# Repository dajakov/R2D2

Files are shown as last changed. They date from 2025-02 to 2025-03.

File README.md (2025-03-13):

# R2D2 Robotic Control System

<div style="display: flex; justify-content: space-between;">
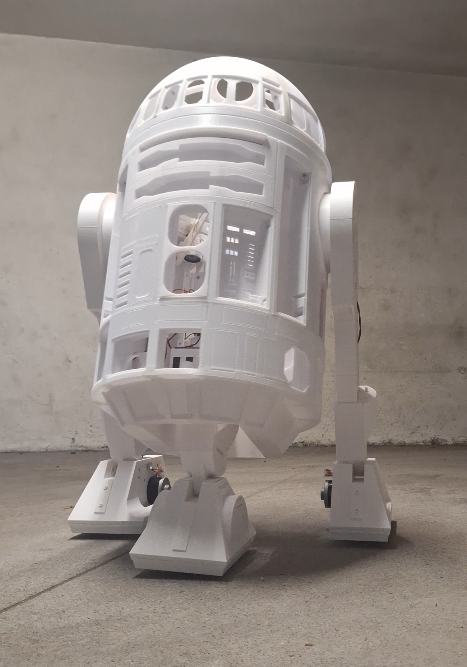
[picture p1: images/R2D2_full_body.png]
  
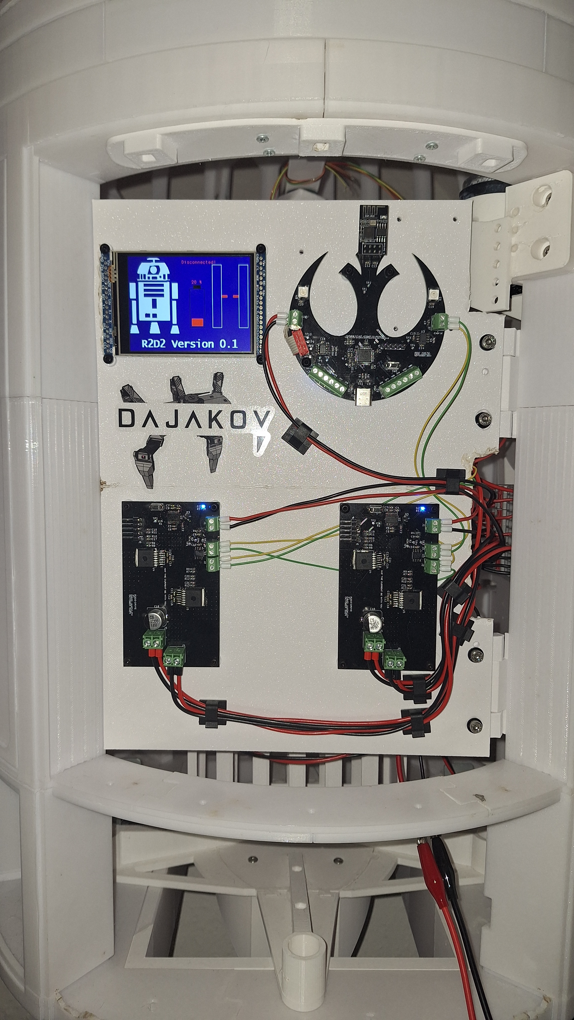
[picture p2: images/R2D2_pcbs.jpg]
  
</div>

This repository contains all source files for a robotic control system designed to control a life-sized R2D2 robot. The 3D models were created by  [Michael Baddeley](https://www.patreon.com/mrbaddeley).

I initiated this project due to the need for a smart and reliable way to control R2D2 via an Android app. I began developing a simple proof-of-concept app in Android Studio, featuring:

- A joystick for velocity control
- Two buttons to rotate the dome
- A text field to display debugging messages

The communication between the hardware and the app occurs via a WebSocket connection to an ESP01.

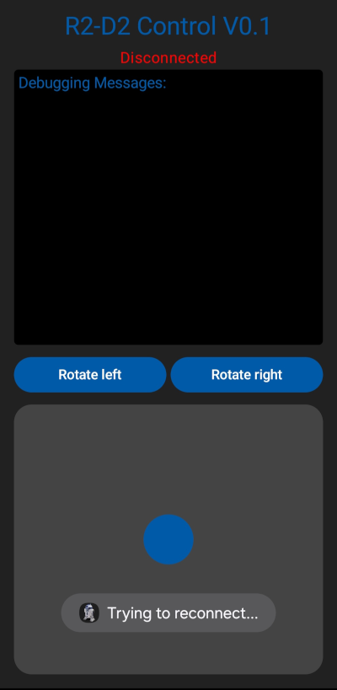
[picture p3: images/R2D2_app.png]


# Hardware

I designed multiple subsystems, each with its own PCB. The brain of every subsystem is a STM32 microcontroller, responsible for fulfilling unique tasks. These PCBs communicate with each other via CAN-bus.

The main PCB serves as the translator for incoming data from the Android app, converting it into low-level commands for the subsystems which control the actual hardware. 

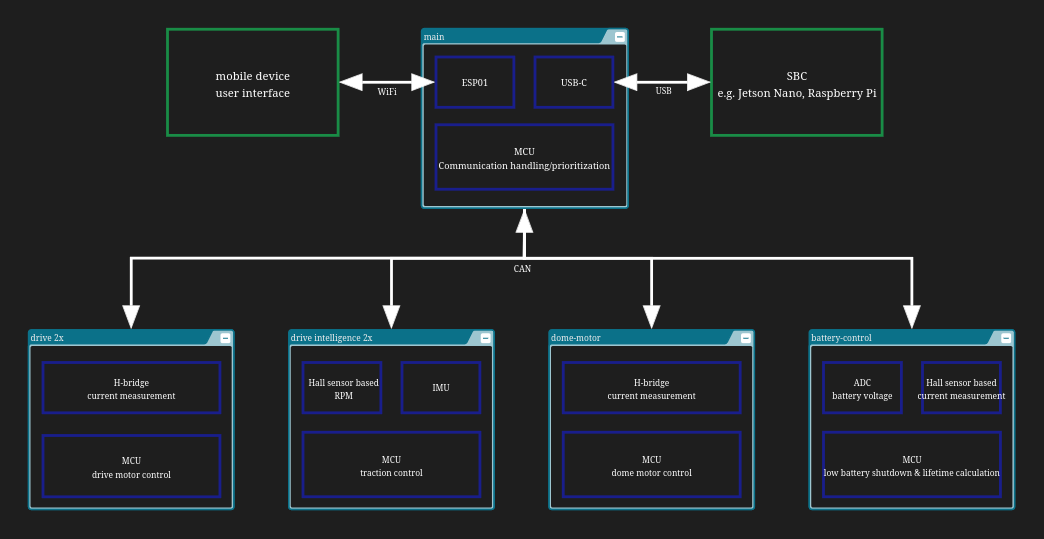
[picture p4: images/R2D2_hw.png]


# Firmware

The STM32 microcontrollers were programmed using STM32CubeIDE. This repository contains the entire CubeIDE project directory for each subsystem.
Each PCB features a 2.54mm male pin header, allowing for easy flashing and debugging via SWD (Serial Wire Debug).

# Development

Hardware:
- [x] Test main PCB
- [x] Test drive PCB
- [ ] Test dome-motor PCB
- [x] Test drive-intelligence PCB
- [ ] Test battery-control PCB

Firmware:
- [x] Velocity control 
- [x] Shut down motors on connection loss to Android App
- [x] Increase CAN frequency

Android App:
- [x] Joystick
- [x] Buttons for dome rotation
- [ ] Add status display (battery state, error indicator)

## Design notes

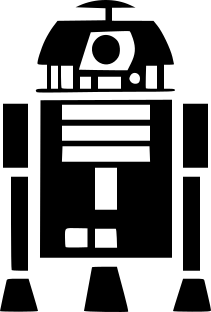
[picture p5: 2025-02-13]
firmware/R2D2 - Main/r2d2-bitmap.bmp

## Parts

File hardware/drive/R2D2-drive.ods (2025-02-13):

Reference | Value | Datasheet | Footprint | Qty | DNP
C1,C3 | 10u | ~ | Capacitor_SMD:C_0603_1608Metric_Pad1.08x0.95mm_HandSolder | 2
C2 | 4.7u | ~ | Capacitor_SMD:C_0603_1608Metric_Pad1.08x0.95mm_HandSolder | 1
C4,C5,C6,C8,C9,C10,C11,C12,C13,C14,C15,C16,C17,C20 | 100n | ~ | Capacitor_SMD:C_0603_1608Metric_Pad1.08x0.95mm_HandSolder | 14
C7 | 1u | ~ | Capacitor_SMD:C_0603_1608Metric_Pad1.08x0.95mm_HandSolder | 1
C18 | 1000u | ~ | Capacitor_SMD:CP_Elec_10x10.5 | 1
C19,C21 | 1n | ~ | Capacitor_SMD:C_0603_1608Metric_Pad1.08x0.95mm_HandSolder | 2
D1 | 1N4001 | ~ | Diode_SMD:D_SMA_Handsoldering | 1
D2 | LED | ~ | LED_SMD:LED_0603_1608Metric_Pad1.05x0.95mm_HandSolder | 1
D3 | BAT54C | http://www.diodes.com/_files/datasheets/ds11005.pdf | Package_TO_SOT_SMD:SOT-23 | 1
J1,J2,J3 | 1751248 |  | 1751248:PHOENIX_1751248 | 3
J4,J5 | 1935776 |  | 1935776:PHOENIX_1935776 | 2
J6 | Conn_01x05_Pin | ~ | Connector_PinHeader_2.54mm:PinHeader_1x05_P2.54mm_Horizontal | 1
R1,R2,R6,R7,R8,R9 | 10k | ~ | Resistor_SMD:R_0603_1608Metric_Pad0.98x0.95mm_HandSolder | 6
R3 | 560 | ~ | Resistor_SMD:R_0603_1608Metric_Pad0.98x0.95mm_HandSolder | 1
R4 | 0 | ~ | Resistor_SMD:R_0603_1608Metric_Pad0.98x0.95mm_HandSolder | 1
R10,R12 | 5k1 | ~ | Resistor_SMD:R_0603_1608Metric_Pad0.98x0.95mm_HandSolder | 2
R11,R13 | 1k | ~ | Resistor_SMD:R_0603_1608Metric_Pad0.98x0.95mm_HandSolder | 2
SW1 | PTS636 SM50J SMTR LFS | PTS636 SM50J SMTR LFS | PTS636:SW_PTS636_CNK | 1
TP1,TP2,TP3,TP4 | TestPoint | ~ | TestPoint:TestPoint_Pad_D1.0mm | 4
U1 | LM1117MP-3.3 | http://www.ti.com/lit/ds/symlink/lm1117.pdf | Package_TO_SOT_SMD:SOT-223-3_TabPin2 | 1
U2 | STM32F042F6Px | https://www.st.com/resource/en/datasheet/stm32f042f6.pdf | Package_SO:TSSOP-20_4.4x6.5mm_P0.65mm | 1
U3 | SN65HVD230 | http://www.ti.com/lit/ds/symlink/sn65hvd230.pdf | Package_SO:SOIC-8_3.9x4.9mm_P1.27mm | 1
U4,U5 | BTN8962TAAUMA1 | BTN8962TAAUMA1 | BTN8962TAAUMA1:PG-TO263-7-1_INF | 2

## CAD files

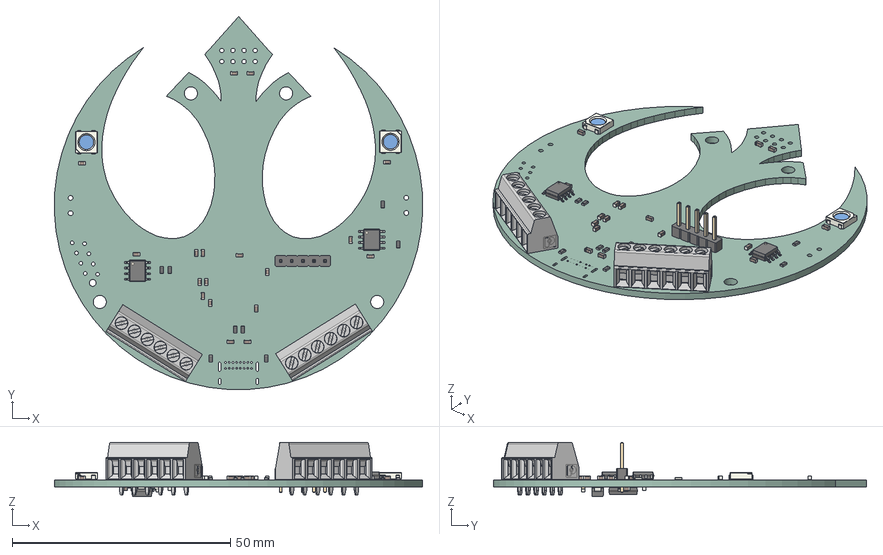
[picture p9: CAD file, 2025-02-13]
hardware/main/R2D2-Main.step
84.3 x 85.4 x 12.5 mm
R_0603_1608Metric x 9
C_0603_1608Metric x 20
LED_WS2812B_PLCC4_50x50mm_P32mm x 2
PinHeader_1x05_P254mm_Vertical
mkds_1-6-3.5 x 2
SOIC_8_39x49mm_P127mm x 2
LED_0603_1608Metric
D_SMA
SOT_223
R2D2-Main_PCB

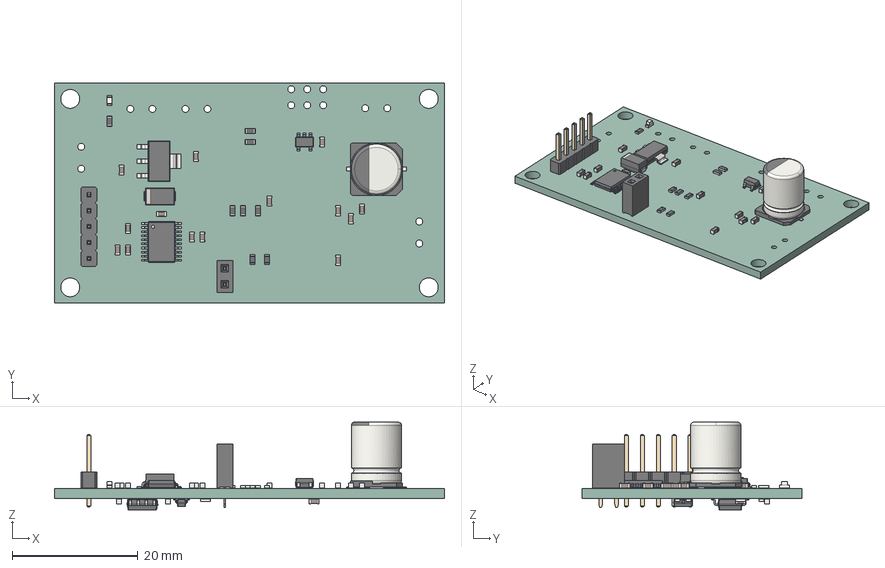
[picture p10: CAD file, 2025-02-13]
hardware/dome-motor/R2D2-dome-motor.step
62.0 x 35.0 x 14.0 mm
C_0603_1608Metric x 17
SOT_23_5
R_0603_1608Metric x 12
TSSOP_20_44x65mm_P065mm
PinHeader_1x05_P254mm_Vertical
SOT_223
LED_0603_1608Metric
CP_Elec_8x105
D_SMA
PinSocket_1x02_P254mm_Vertical
SOIC_8_39x49mm_P127mm
SOT_23
R2D2-dome-motor_PCB

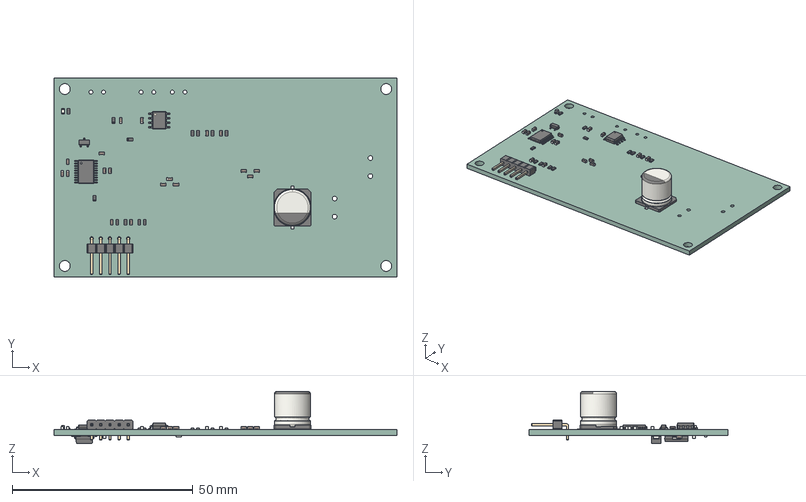
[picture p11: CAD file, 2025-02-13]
hardware/drive/R2D2-drive.step
95.0 x 55.0 x 14.4 mm
CP_Elec_10x105
R_0603_1608Metric x 13
C_0603_1608Metric x 20
SOIC_8_39x49mm_P127mm
PinHeader_1x05_P254mm_Horizontal
LED_0603_1608Metric
TSSOP_20_44x65mm_P065mm
SOT_23
D_SMA
SOT_223
R2D2-drive_PCB

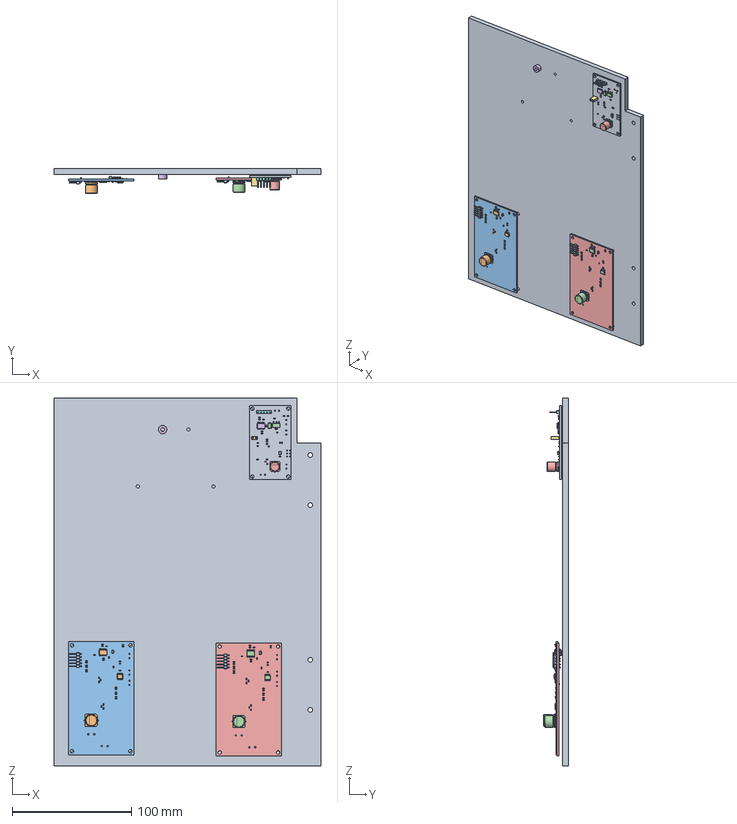
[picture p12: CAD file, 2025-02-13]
hardware/main/Unnamed.FCStd
224.0 x 21.2 x 309.0 mm
C_0603_1608Metric040
C_0603_1608Metric042
SOT_23_5
R_0603_1608Metric018
TSSOP_20_44x65mm_P065mm
C_0603_1608Metric044
PinHeader_1x05_P254mm_Vertical001
R_0603_1608Metric020
R_0603_1608Metric022
R_0603_1608Metric024
SOT_224
R_0603_1608Metric026
C_0603_1608Metric046
C_0603_1608Metric048
C_0603_1608Metric050
LED_0603_1608Metric002
C_0603_1608Metric052
C_0603_1608Metric054
R_0603_1608Metric028
CP_Elec_8x105
C_0603_1608Metric056
C_0603_1608Metric058
C_0603_1608Metric060
R_0603_1608Metric030
R_0603_1608Metric032
C_0603_1608Metric062
D_SMA002
C_0603_1608Metric064
C_0603_1608Metric066
PinSocket_1x02_P254mm_Vertical
C_0603_1608Metric068
R_0603_1608Metric034
R_0603_1608Metric036
R_0603_1608Metric038
C_0603_1608Metric070
C_0603_1608Metric072
SOIC_8_39x49mm_P127mm002
R_0603_1608Metric040
SOT_23
R2D2-dome-motor_PCB
CP_Elec_10x105
R_0603_1608Metric042
C_0603_1608Metric074
R_0603_1608Metric044
R_0603_1608Metric046
R_0603_1608Metric048
R_0603_1608Metric050
C_0603_1608Metric076
SOIC_8_39x49mm_P127mm003
C_0603_1608Metric078
R_0603_1608Metric052
C_0603_1608Metric080
R_0603_1608Metric054
C_0603_1608Metric082
R_0603_1608Metric056
PinHeader_1x05_P254mm_Horizontal
R_0603_1608Metric058
C_0603_1608Metric084
R_0603_1608Metric060
C_0603_1608Metric086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

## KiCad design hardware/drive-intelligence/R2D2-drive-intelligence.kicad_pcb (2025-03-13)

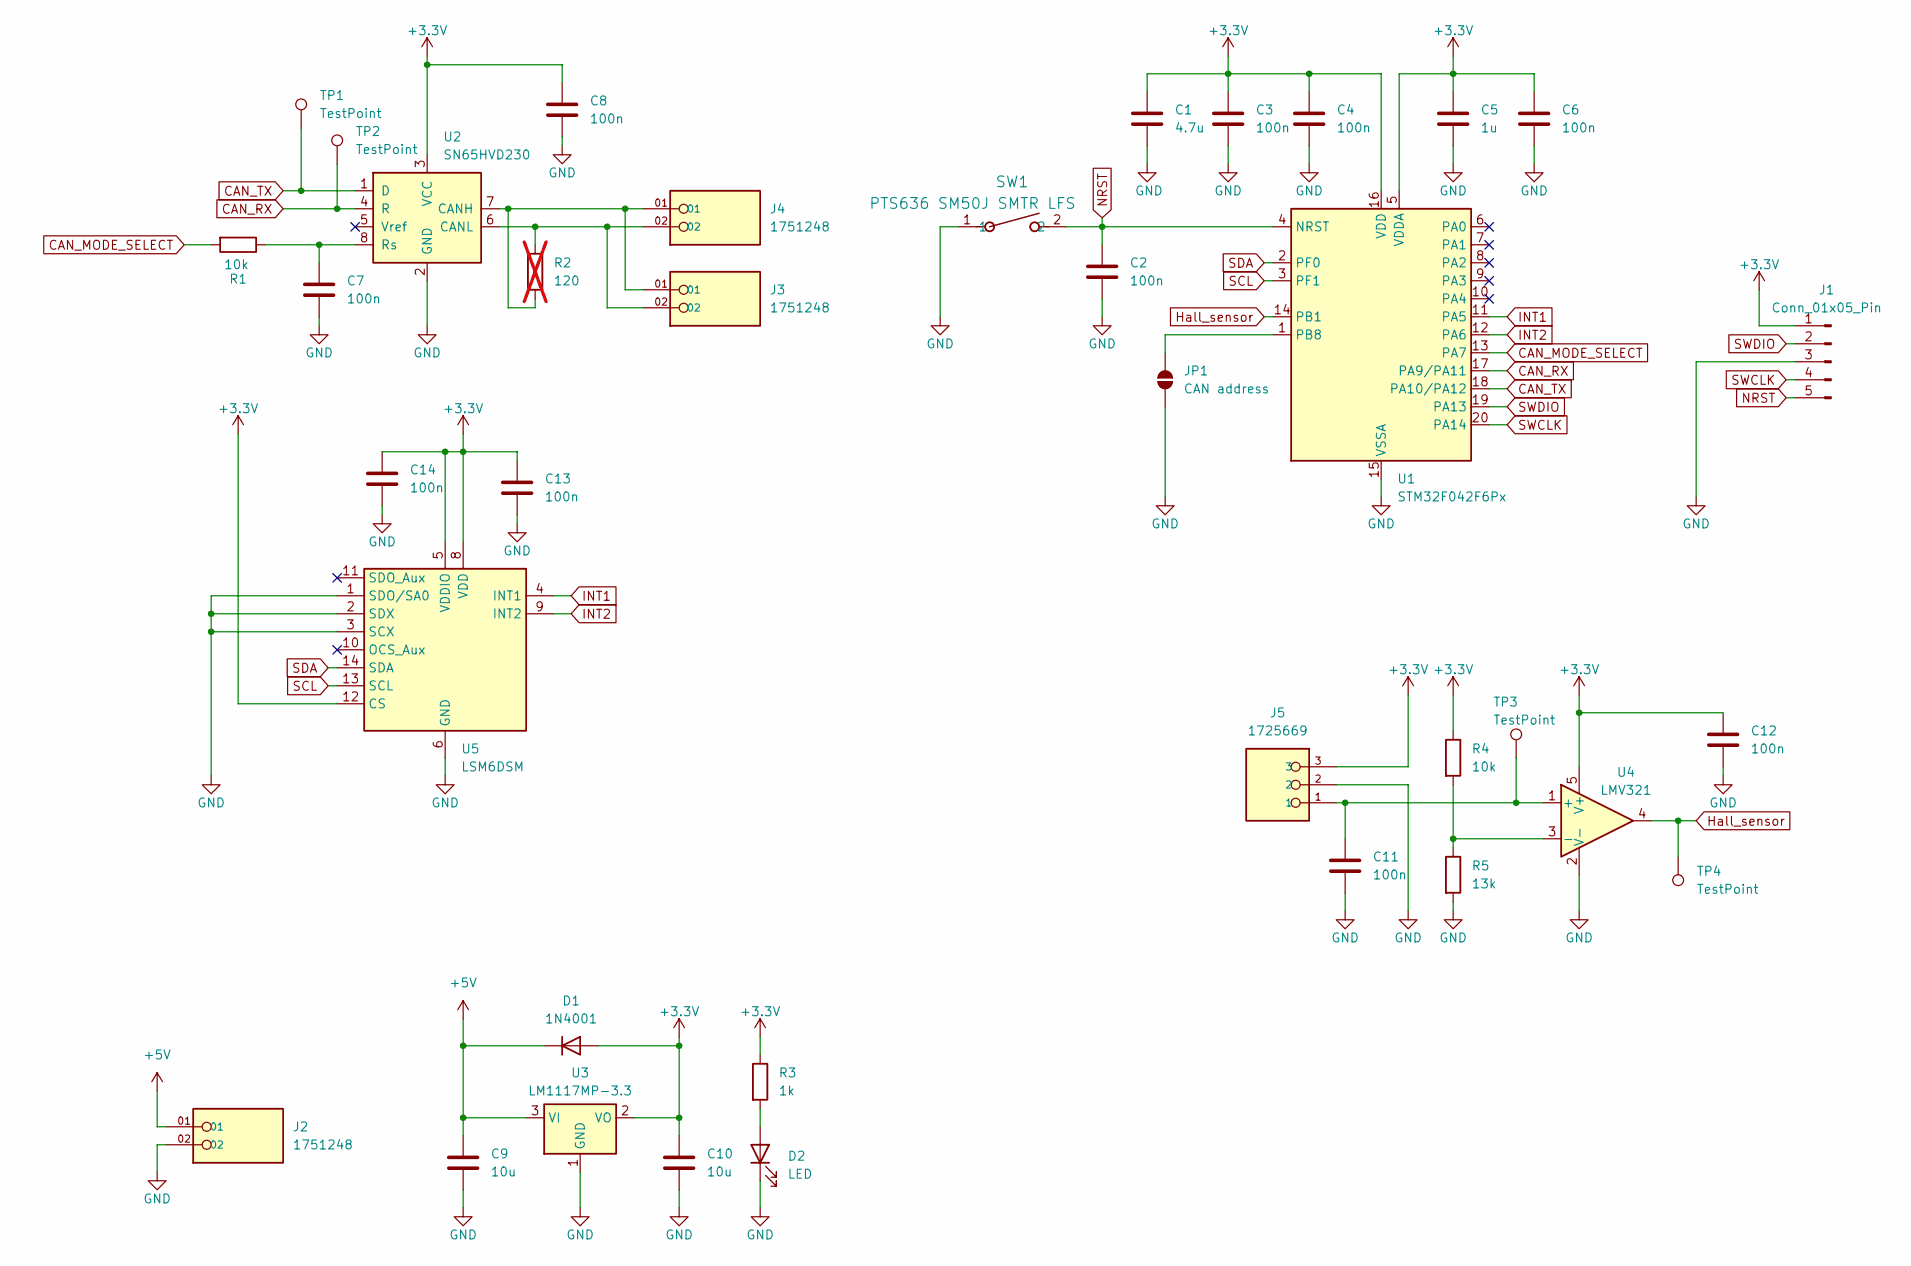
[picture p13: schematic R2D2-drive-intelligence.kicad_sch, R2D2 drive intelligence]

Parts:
C1: 4.7u; C_0603_1608Metric_Pad1.08x0.95mm_HandSolder
C2, C3, C4, C6, C7, C8, C11, C12, C13, C14: 100n; C_0603_1608Metric_Pad1.08x0.95mm_HandSolder
C5: 1u; C_0603_1608Metric_Pad1.08x0.95mm_HandSolder
C9, C10: 10u; C_0603_1608Metric_Pad1.08x0.95mm_HandSolder
D1: 1N4001; D_SMA_Handsoldering
D2: LED; LED_0603_1608Metric_Pad1.05x0.95mm_HandSolder
J1: Conn_01x05_Pin; PinHeader_1x05_P2.54mm_Horizontal
J2, J3, J4: 1751248; PHOENIX_1751248; PARTREV 03.03.2021
J5: 1725669; PHOENIX_1725669; PARTREV 03.03.2021
JP1: CAN address; SolderJumper-2_P1.3mm_Open_TrianglePad1.0x1.5mm
R1, R4: 10k; R_0603_1608Metric_Pad0.98x0.95mm_HandSolder
R2: 120; R_0603_1608Metric_Pad0.98x0.95mm_HandSolder; not fitted
R3: 1k; R_0603_1608Metric_Pad0.98x0.95mm_HandSolder
R5: 13k; R_0603_1608Metric_Pad0.98x0.95mm_HandSolder
SW1: PTS636 SM50J SMTR LFS; SW_PTS636_CNK
TP1, TP2, TP3, TP4: TestPoint; TestPoint_Pad_D1.0mm
U1: STM32F042F6Px; TSSOP-20_4.4x6.5mm_P0.65mm
U2: SN65HVD230; SOIC-8_3.9x4.9mm_P1.27mm
U3: LM1117MP-3.3; SOT-223-3_TabPin2
U4: LMV321; SOT-23-5
U5: LSM6DSM; LGA-14_3x2.5mm_P0.5mm_LayoutBorder3x4y

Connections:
+3.3V: C1.1, C3.1, C4.1, C5.1, C6.1, C8.1, C10.1, C12.1, C13.1, C14.1, D1.2 (A), J1.1, J5.3, R3.1, R4.1, U1.5 (VDDA), U1.16 (VDD), U2.3 (VCC), U3.2 (VO), U4.5 (V+), U5.5 (VDDIO), U5.8 (VDD), U5.12 (CS)
+5V: C9.1, D1.1 (K), J2.01, U3.3 (VI)
CAN_MODE_SELECT: R1.2, U1.13 (PA7)
CAN_RX: TP2.1, U1.17 (PA9/PA11), U2.4 (R)
CAN_TX: TP1.1, U1.18 (PA10/PA12), U2.1 (D)
GND: C1.2, C2.2, C3.2, C4.2, C5.2, C6.2, C7.2, C8.2, C9.2, C10.2, C11.2, C12.2, C13.2, C14.2, D2.1 (K), J1.3, J2.02, J5.2, JP1.1 (A), R5.2, SW1.1, U1.15 (VSSA), U2.2 (GND), U3.1 (GND), U4.2 (V-), U5.1 (SDO/SA0), U5.2 (SDX), U5.3 (SCX), U5.6 (GND), U5.7 (GND)
Hall_sensor: TP4.1, U1.14 (PB1), U4.4
INT1: U1.11 (PA5), U5.4 (INT1)
INT2: U1.12 (PA6), U5.9 (INT2)
NRST: C2.1, J1.5, SW1.2, U1.4 (NRST)
unnamed: D2.2 (A), R3.2
unnamed: JP1.2 (B), U1.1 (PB8)
unnamed: J3.01, J4.01, R2.2, U2.7 (CANH)
unnamed: J3.02, J4.02, R2.1, U2.6 (CANL)
unnamed: C7.1, R1.1, U2.8 (Rs)
unnamed: C11.1, J5.1, TP3.1, U4.1 (+)
unnamed: R4.2, R5.1, U4.3 (-)
SCL: U1.3 (PF1), U5.13 (SCL)
SDA: U1.2 (PF0), U5.14 (SDA)
SWCLK: J1.4, U1.20 (PA14)
SWDIO: J1.2, U1.19 (PA13)

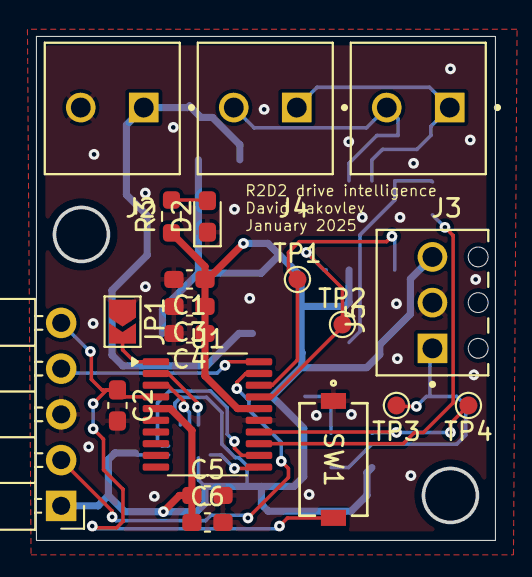
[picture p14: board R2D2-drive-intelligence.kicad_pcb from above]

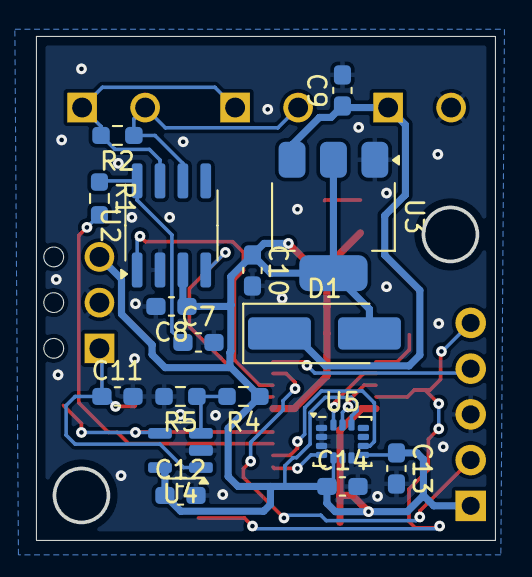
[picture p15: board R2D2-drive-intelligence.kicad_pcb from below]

Board: 2 copper layers, 25.5 x 28.0 mm, 37 parts (17 on the bottom side), 21 nets.

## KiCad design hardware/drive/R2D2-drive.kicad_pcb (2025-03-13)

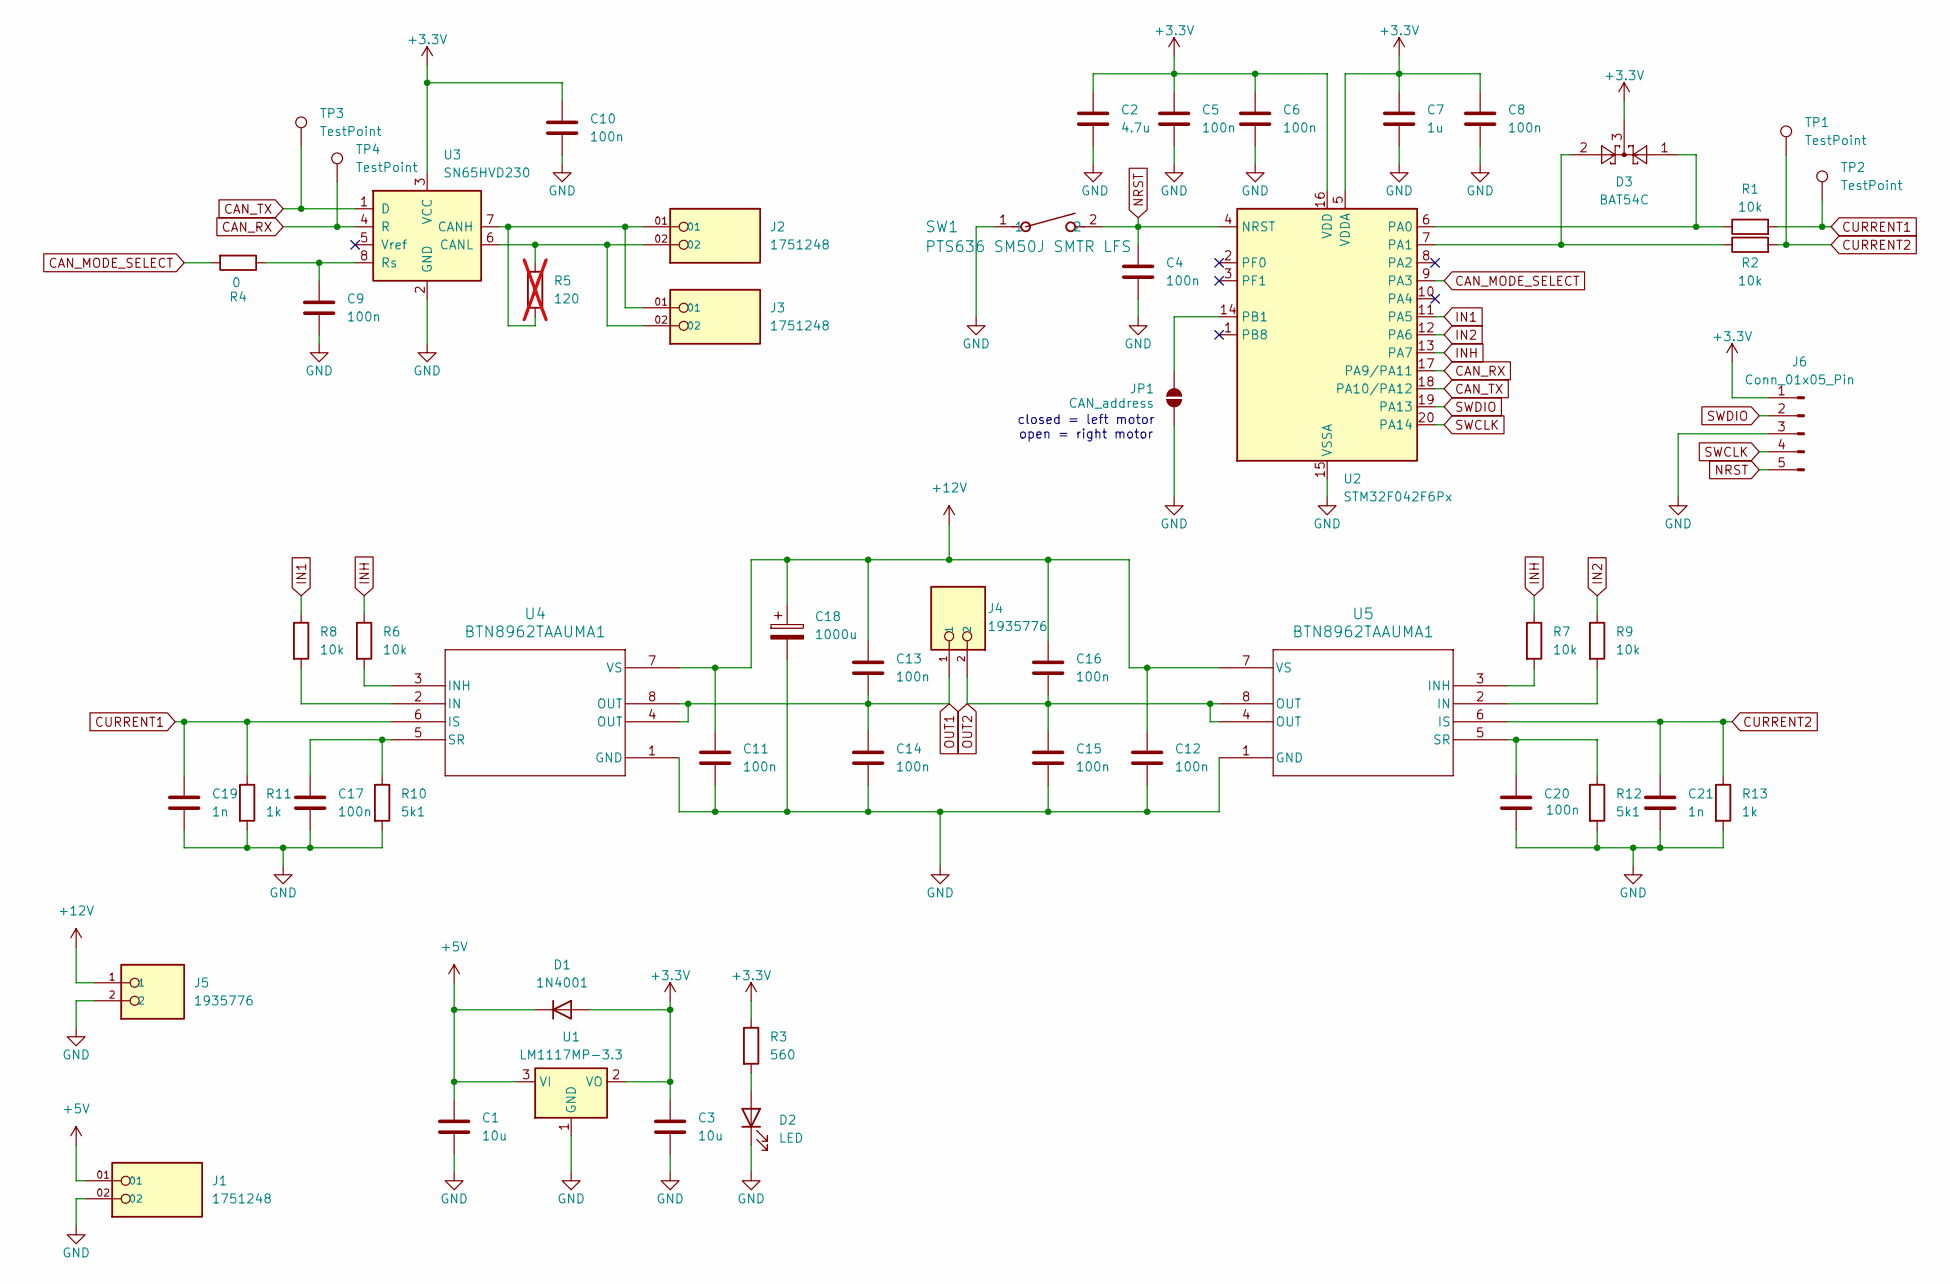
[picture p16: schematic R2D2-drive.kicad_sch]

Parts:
C1, C3: 10u; C_0603_1608Metric_Pad1.08x0.95mm_HandSolder
C2: 4.7u; C_0603_1608Metric_Pad1.08x0.95mm_HandSolder
C4, C5, C6, C8, C9, C10, C11, C12, C13, C14, C15, C16, C17, C20: 100n; C_0603_1608Metric_Pad1.08x0.95mm_HandSolder
C7: 1u; C_0603_1608Metric_Pad1.08x0.95mm_HandSolder
C18: 1000u; CP_Elec_10x10.5
C19, C21: 1n; C_0603_1608Metric_Pad1.08x0.95mm_HandSolder
D1: 1N4001; D_SMA_Handsoldering
D2: LED; LED_0603_1608Metric_Pad1.05x0.95mm_HandSolder
D3: BAT54C; SOT-23
J1, J2, J3: 1751248; PHOENIX_1751248; PARTREV 03.03.2021
J4, J5: 1935776; PHOENIX_1935776; PARTREV 19.10.2016
J6: Conn_01x05_Pin; PinHeader_1x05_P2.54mm_Horizontal
JP1: CAN_address; SolderJumper-2_P1.3mm_Open_TrianglePad1.0x1.5mm
R1, R2, R6, R7, R8, R9: 10k; R_0603_1608Metric_Pad0.98x0.95mm_HandSolder
R3: 560; R_0603_1608Metric_Pad0.98x0.95mm_HandSolder
R4: 0; R_0603_1608Metric_Pad0.98x0.95mm_HandSolder
R5: 120; R_0603_1608Metric_Pad0.98x0.95mm_HandSolder; not fitted
R10, R12: 5k1; R_0603_1608Metric_Pad0.98x0.95mm_HandSolder
R11, R13: 1k; R_0603_1608Metric_Pad0.98x0.95mm_HandSolder
SW1: PTS636 SM50J SMTR LFS; SW_PTS636_CNK
TP1, TP2, TP3, TP4: TestPoint; TestPoint_Pad_D1.0mm
U1: LM1117MP-3.3; SOT-223-3_TabPin2
U2: STM32F042F6Px; TSSOP-20_4.4x6.5mm_P0.65mm
U3: SN65HVD230; SOIC-8_3.9x4.9mm_P1.27mm
U4, U5: BTN8962TAAUMA1; PG-TO263-7-1_INF

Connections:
+3.3V: C2.1, C3.1, C5.1, C6.1, C7.1, C8.1, C10.1, D1.2 (A), D3.3, J6.1, R3.1, U1.2 (VO), U2.5 (VDDA), U2.16 (VDD), U3.3 (VCC)
+5V: C1.1, D1.1 (K), J1.01, U1.3 (VI)
+12V: C11.1, C12.1, C13.1, C16.1, C18.1, J5.1, U4.7 (VS), U5.7 (VS)
CAN_MODE_SELECT: R4.2, U2.9 (PA3)
CAN_RX: TP4.1, U2.17 (PA9/PA11), U3.4 (R)
CAN_TX: TP3.1, U2.18 (PA10/PA12), U3.1 (D)
CURRENT1: C19.1, R1.2, R11.1, TP2.1, U4.6 (IS)
CURRENT2: C21.1, R2.2, R13.1, TP1.1, U5.6 (IS)
GND: C1.2, C2.2, C3.2, C4.2, C5.2, C6.2, C7.2, C8.2, C9.2, C10.2, C11.2, C12.2, C14.2, C15.2, C17.2, C18.2, C19.2, C20.2, C21.2, D2.1 (K), J1.02, J5.2, J6.3, JP1.1 (A), R10.2, R11.2, R12.2, R13.2, SW1.1, U1.1 (GND), U2.15 (VSSA), U3.2 (GND), U4.1 (GND), U5.1 (GND)
IN1: R8.1, U2.11 (PA5)
IN2: R9.1, U2.12 (PA6)
INH: R6.1, R7.1, U2.13 (PA7)
NRST: C4.1, J6.5, SW1.2, U2.4 (NRST)
unnamed: D2.2 (A), R3.2
unnamed: JP1.2 (B), U2.14 (PB1)
unnamed: D3.1, R1.1, U2.6 (PA0)
unnamed: D3.2, R2.1, U2.7 (PA1)
unnamed: J2.01, J3.01, R5.2, U3.7 (CANH)
unnamed: J2.02, J3.02, R5.1, U3.6 (CANL)
unnamed: C9.1, R4.1, U3.8 (Rs)
unnamed: R8.2, U4.2 (IN)
unnamed: R6.2, U4.3 (INH)
unnamed: C17.1, R10.1, U4.5 (SR)
unnamed: R9.2, U5.2 (IN)
unnamed: R7.2, U5.3 (INH)
unnamed: C20.1, R12.1, U5.5 (SR)
OUT1: C13.2, C14.1, J4.1, U4.4 (OUT), U4.8 (OUT)
OUT2: C15.1, C16.2, J4.2, U5.4 (OUT), U5.8 (OUT)
SWCLK: J6.4, U2.20 (PA14)
SWDIO: J6.2, U2.19 (PA13)

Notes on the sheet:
closed = left motor open = right motor

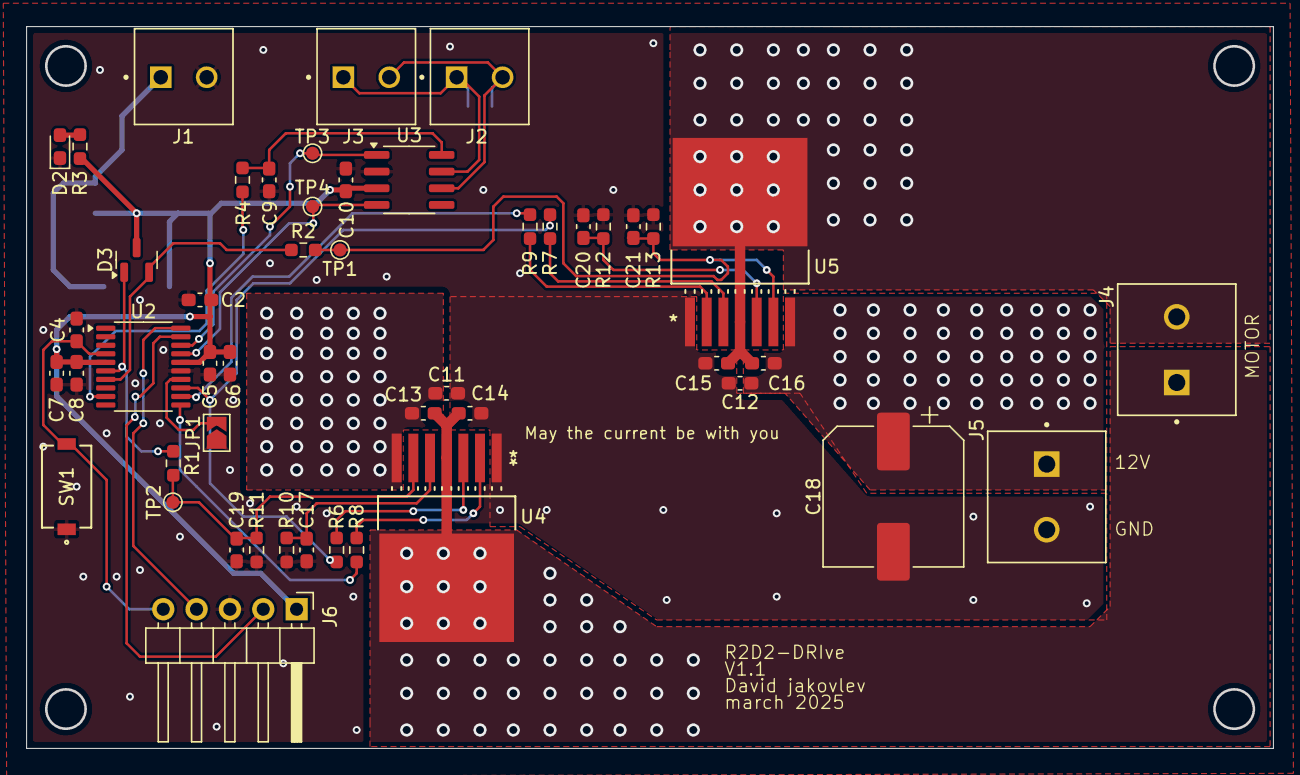
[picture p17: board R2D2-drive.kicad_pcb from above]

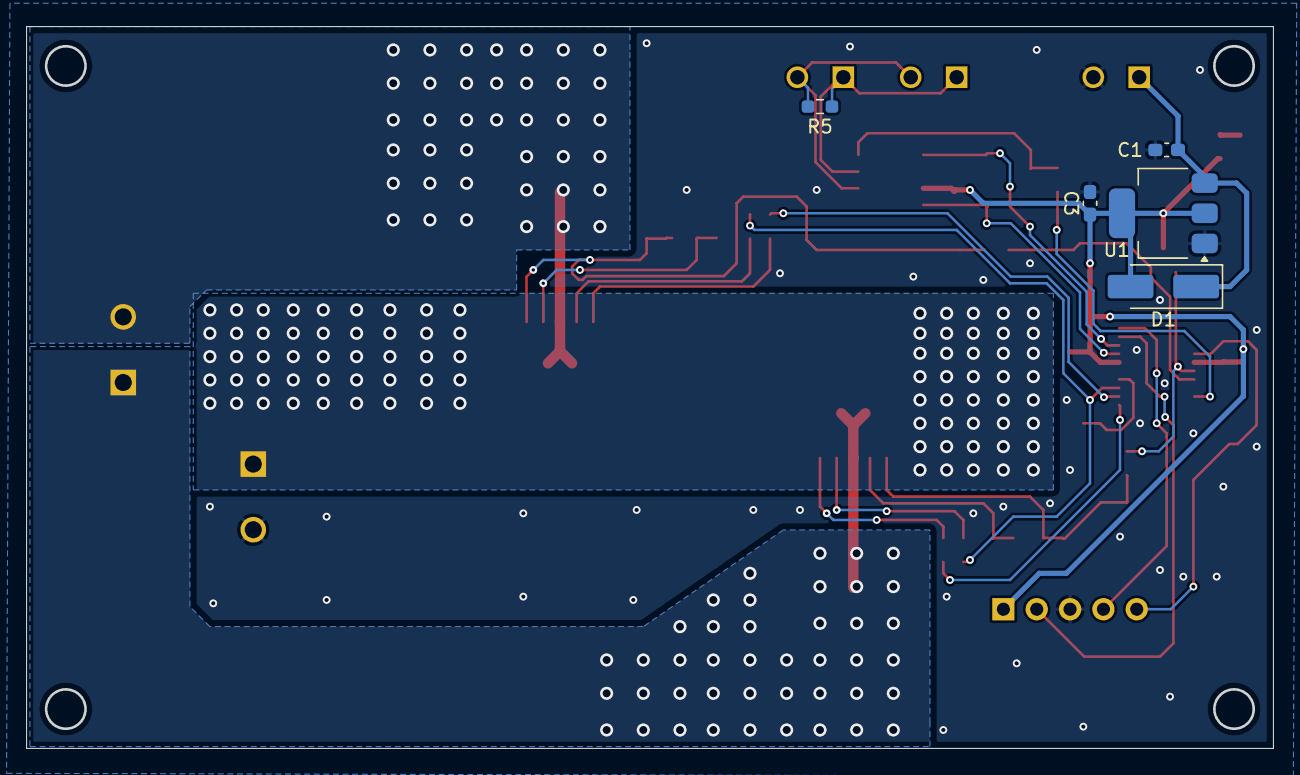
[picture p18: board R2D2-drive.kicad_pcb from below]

Board: 2 copper layers, 95.0 x 55.0 mm, 54 parts (5 on the bottom side), 30 nets.

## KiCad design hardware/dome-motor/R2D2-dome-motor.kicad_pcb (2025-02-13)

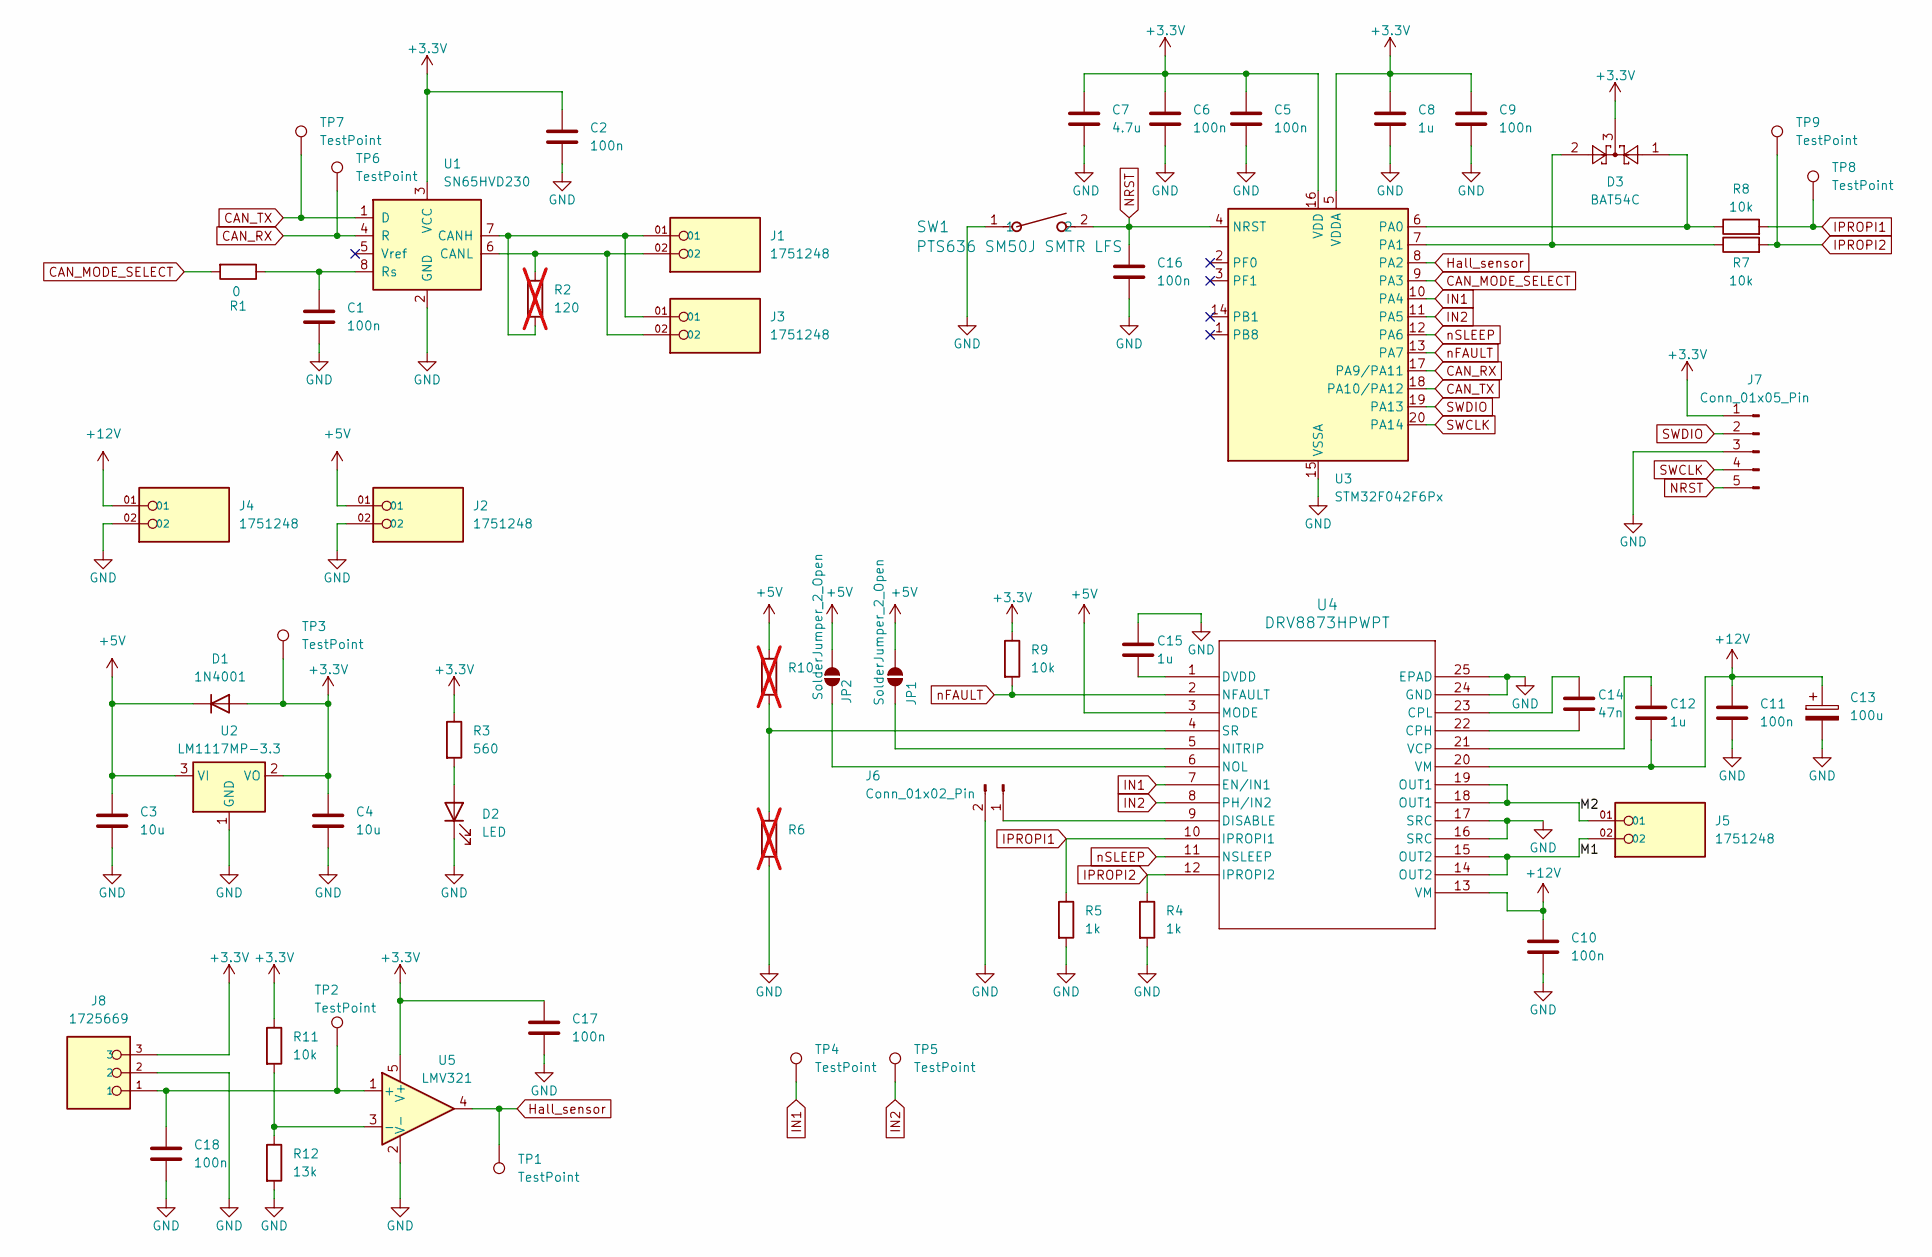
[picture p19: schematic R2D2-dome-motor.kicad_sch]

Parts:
C1, C2, C5, C6, C9, C16, C17, C18: 100n; C_0603_1608Metric_Pad1.08x0.95mm_HandSolder
C3, C4: 10u; C_0603_1608Metric_Pad1.08x0.95mm_HandSolder
C7: 4.7u; C_0603_1608Metric_Pad1.08x0.95mm_HandSolder
C8, C15: 1u; C_0603_1608Metric_Pad1.08x0.95mm_HandSolder
C10, C11: 100n; C_0603_1608Metric
C12: 1u; C_0603_1608Metric
C13: 100u; CP_Elec_8x10.5
C14: 47n; C_0603_1608Metric
D1: 1N4001; D_SMA_Handsoldering
D2: LED; LED_0603_1608Metric_Pad1.05x0.95mm_HandSolder
D3: BAT54C; SOT-23
J1, J2, J3, J4, J5: 1751248; PHOENIX_1751248; PARTREV 03.03.2021
J6: Conn_01x02_Pin; PinSocket_1x02_P2.54mm_Vertical
J7: Conn_01x05_Pin; PinHeader_1x05_P2.54mm_Vertical
J8: 1725669; PHOENIX_1725669; PARTREV 03.03.2021
JP1, JP2: SolderJumper_2_Open; SolderJumper-2_P1.3mm_Open_TrianglePad1.0x1.5mm
R1: 0; R_0603_1608Metric_Pad0.98x0.95mm_HandSolder
R2: 120; R_0603_1608Metric_Pad0.98x0.95mm_HandSolder; not fitted
R3: 560; R_0603_1608Metric_Pad0.98x0.95mm_HandSolder
R4, R5: 1k; R_0603_1608Metric_Pad0.98x0.95mm_HandSolder
R6, R10: R_0603_1608Metric_Pad0.98x0.95mm_HandSolder; not fitted
R7, R8, R9, R11: 10k; R_0603_1608Metric_Pad0.98x0.95mm_HandSolder
R12: 13k; R_0603_1608Metric_Pad0.98x0.95mm_HandSolder
SW1: PTS636 SM50J SMTR LFS; SW_PTS636_CNK
TP1, TP2, TP3, TP4, TP5, TP6, TP7, TP8, TP9: TestPoint; TestPoint_Pad_D1.0mm
U1: SN65HVD230; SOIC-8_3.9x4.9mm_P1.27mm
U2: LM1117MP-3.3; SOT-223-3_TabPin2
U3: STM32F042F6Px; TSSOP-20_4.4x6.5mm_P0.65mm
U4: DRV8873HPWPT; PWP24_TEX-M
U5: LMV321; SOT-23-5

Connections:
+3.3V: C2.1, C4.1, C5.1, C6.1, C7.1, C8.1, C9.1, C17.1, D1.2 (A), D3.3, J7.1, J8.3, R3.1, R9.1, R11.1, TP3.1, U1.3 (VCC), U2.2 (VO), U3.5 (VDDA), U3.16 (VDD), U5.5 (V+)
+5V: C3.1, D1.1 (K), J2.01, JP1.2 (B), JP2.2 (B), R10.1, U2.3 (VI), U4.3 (MODE)
+12V: C10.1, C11.1, C12.2, C13.1, J4.01, U4.13 (VM), U4.20 (VM)
/M1: J5.02, U4.14 (OUT2), U4.15 (OUT2)
/M2: J5.01, U4.18 (OUT1), U4.19 (OUT1)
CAN_MODE_SELECT: R1.2, U3.9 (PA3)
CAN_RX: TP6.1, U1.4 (R), U3.17 (PA9/PA11)
CAN_TX: TP7.1, U1.1 (D), U3.18 (PA10/PA12)
GND: C1.2, C2.2, C3.2, C4.2, C5.2, C6.2, C7.2, C8.2, C9.2, C10.2, C11.2, C13.2, C15.1, C16.2, C17.2, C18.2, D2.1 (K), J2.02, J4.02, J6.2, J7.3, J8.2, R4.2, R5.2, R6.2, R12.2, SW1.1, U1.2 (GND), U2.1 (GND), U3.15 (VSSA), U4.16 (SRC), U4.17 (SRC), U4.24 (GND), U4.25 (EPAD), U5.2 (V-)
Hall_sensor: TP1.1, U3.8 (PA2), U5.4
IN1: TP4.1, U3.10 (PA4), U4.7 (EN/IN1)
IN2: TP5.1, U3.11 (PA5), U4.8 (PH/IN2)
IPROPI1: R5.1, R8.2, TP8.1, U4.10 (IPROPI1)
IPROPI2: R4.1, R7.2, TP9.1, U4.12 (IPROPI2)
NRST: C16.1, J7.5, SW1.2, U3.4 (NRST)
unnamed: D2.2 (A), R3.2
unnamed: J6.1, U4.9 (DISABLE)
unnamed: JP1.1 (A), U4.5 (NITRIP)
unnamed: JP2.1 (A), U4.6 (NOL)
unnamed: J1.01, J3.01, R2.2, U1.7 (CANH)
unnamed: J1.02, J3.02, R2.1, U1.6 (CANL)
unnamed: C1.1, R1.1, U1.8 (Rs)
unnamed: D3.1, R8.1, U3.6 (PA0)
unnamed: D3.2, R7.1, U3.7 (PA1)
unnamed: C14.2, U4.22 (CPH)
unnamed: C14.1, U4.23 (CPL)
unnamed: C15.2, U4.1 (DVDD)
unnamed: R6.1, R10.2, U4.4 (SR)
unnamed: C12.1, U4.21 (VCP)
unnamed: C18.1, J8.1, TP2.1, U5.1 (+)
unnamed: R11.2, R12.1, U5.3 (-)
SWCLK: J7.4, U3.20 (PA14)
SWDIO: J7.2, U3.19 (PA13)
nFAULT: R9.2, U3.13 (PA7), U4.2 (NFAULT)
nSLEEP: U3.12 (PA6), U4.11 (NSLEEP)

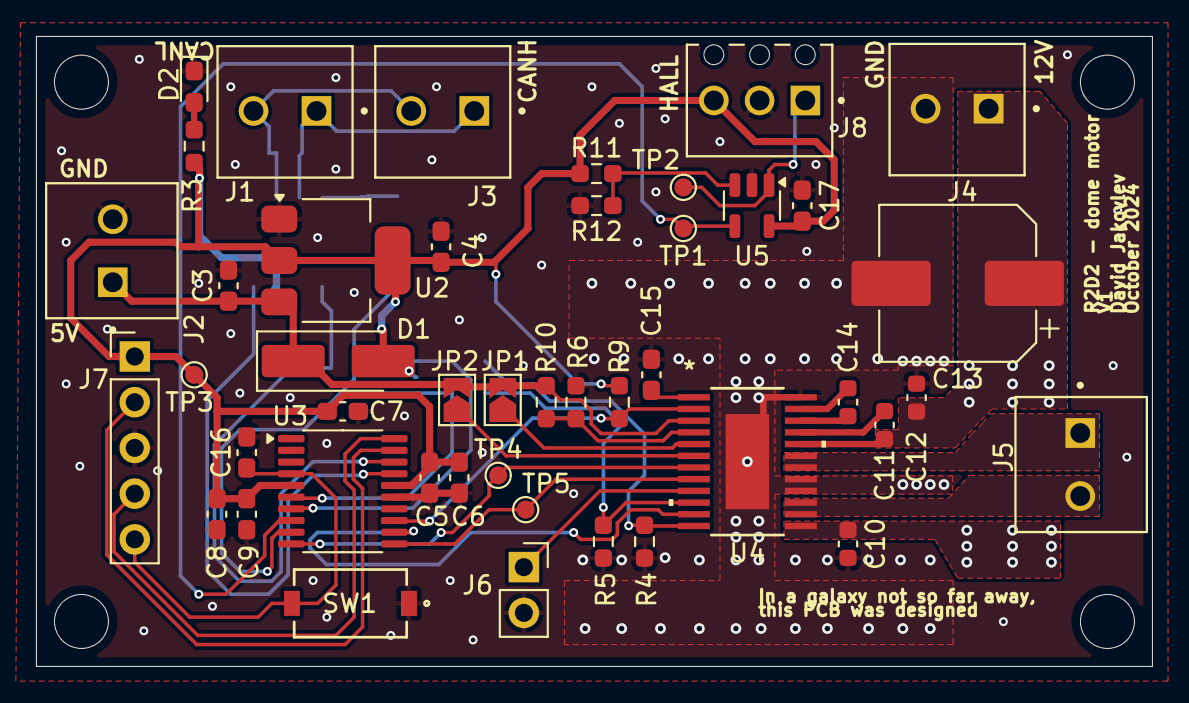
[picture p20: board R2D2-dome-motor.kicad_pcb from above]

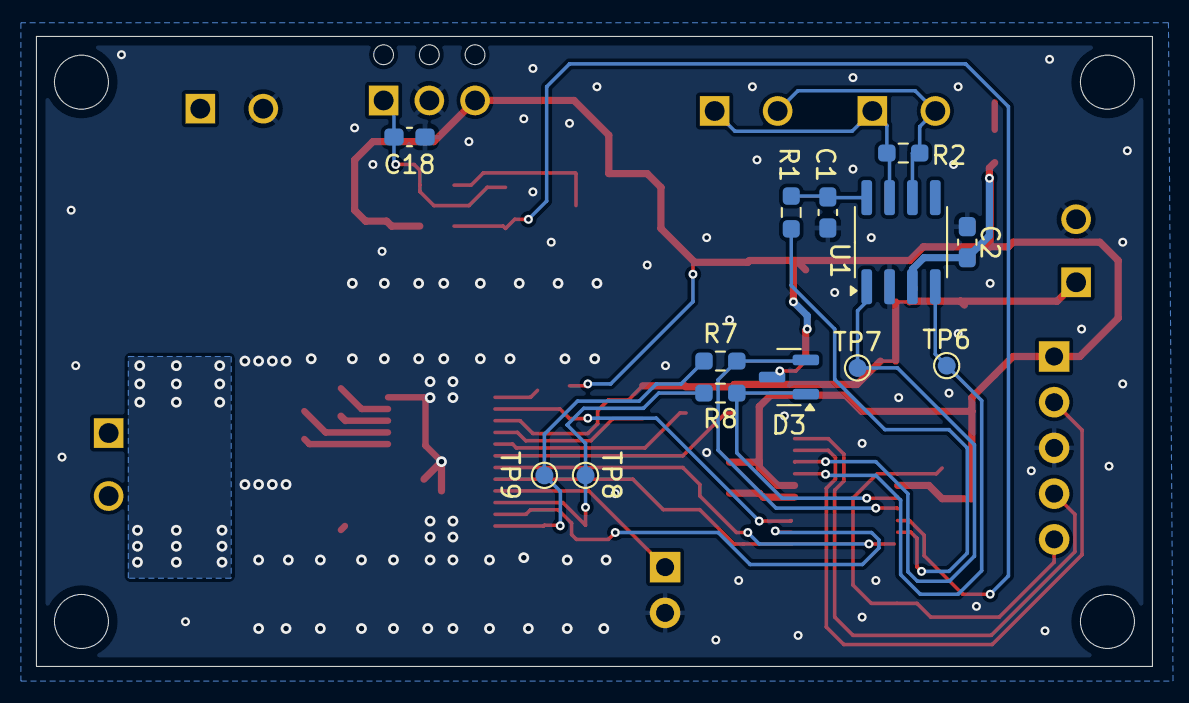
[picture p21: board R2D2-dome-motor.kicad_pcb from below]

Board: 2 copper layers, 62.0 x 35.0 mm, 58 parts (13 on the bottom side), 35 nets.

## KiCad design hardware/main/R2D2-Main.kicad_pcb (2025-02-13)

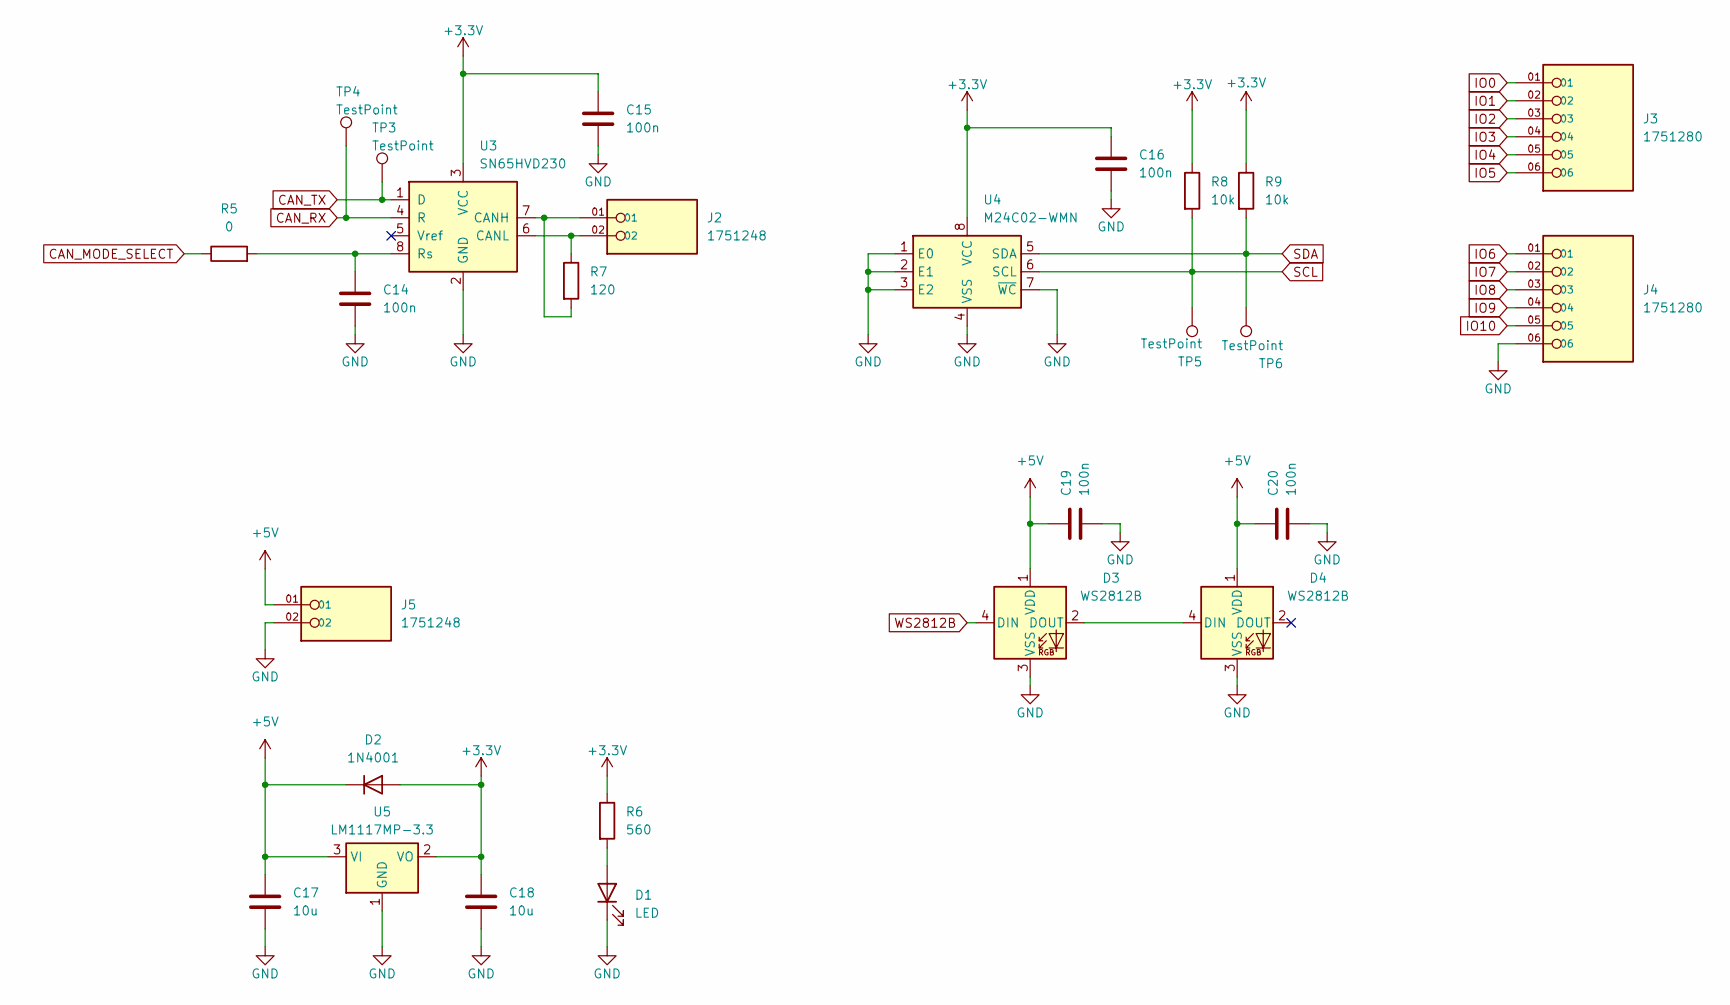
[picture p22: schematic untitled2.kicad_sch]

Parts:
C14, C15, C16, C19, C20: 100n; C_0603_1608Metric_Pad1.08x0.95mm_HandSolder
C17, C18: 10u; C_0603_1608Metric_Pad1.08x0.95mm_HandSolder
D1: LED; LED_0603_1608Metric_Pad1.05x0.95mm_HandSolder
D2: 1N4001; D_SMA_Handsoldering
D3, D4: WS2812B; LED_WS2812B_PLCC4_5.0x5.0mm_P3.2mm
J2, J5: 1751248; PHOENIX_1751248; PARTREV 03.03.2021
J3, J4: 1751280; PHOENIX_1751280; PARTREV 03.03.2021
R5: 0; R_0603_1608Metric_Pad0.98x0.95mm_HandSolder
R6: 560; R_0603_1608Metric_Pad0.98x0.95mm_HandSolder
R7: 120; R_0603_1608Metric_Pad0.98x0.95mm_HandSolder
R8, R9: 10k; R_0603_1608Metric_Pad0.98x0.95mm_HandSolder
TP3, TP4, TP5, TP6: TestPoint; TestPoint_Pad_D1.0mm
U3: SN65HVD230; SOIC-8_3.9x4.9mm_P1.27mm
U4: M24C02-WMN; SOIC-8_3.9x4.9mm_P1.27mm
U5: LM1117MP-3.3; SOT-223-3_TabPin2

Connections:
+3.3V: C15.1, C16.1, C18.1, D2.2 (A), R6.1, R8.1, R9.1, U3.3 (VCC), U4.8 (VCC), U5.2 (VO); also elsewhere on the board
+5V: C17.1, C19.1, C20.1, D2.1 (K), D3.1 (VDD), D4.1 (VDD), J5.01, U5.3 (VI)
CAN_MODE_SELECT: R5.1; also elsewhere on the board
CAN_RX: TP4.1, U3.4 (R); also elsewhere on the board
CAN_TX: TP3.1, U3.1 (D); also elsewhere on the board
GND: C14.2, C15.2, C16.2, C17.2, C18.2, C19.2, C20.2, D1.1 (K), D3.3 (VSS), D4.3 (VSS), J4.06, J5.02, U3.2 (GND), U4.1 (E0), U4.2 (E1), U4.3 (E2), U4.4 (VSS), U4.7 (~WC), U5.1 (GND); also elsewhere on the board
IO0: J3.01; also elsewhere on the board
IO1: J3.02; also elsewhere on the board
IO2: J3.03; also elsewhere on the board
IO3: J3.04; also elsewhere on the board
IO4: J3.05; also elsewhere on the board
IO5: J3.06; also elsewhere on the board
IO6: J4.01; also elsewhere on the board
IO7: J4.02; also elsewhere on the board
IO8: J4.03; also elsewhere on the board
IO9: J4.04; also elsewhere on the board
IO10: J4.05; also elsewhere on the board
unnamed: D1.2 (A), R6.2
unnamed: D3.2 (DOUT), D4.4 (DIN)
unnamed: J2.01, R7.2, U3.7 (CANH)
unnamed: J2.02, R7.1, U3.6 (CANL)
unnamed: C14.1, R5.2, U3.8 (Rs)
SCL: R8.2, TP5.1, U4.6 (SCL); also elsewhere on the board
SDA: R9.2, TP6.1, U4.5 (SDA); also elsewhere on the board
WS2812B: D3.4 (DIN); also elsewhere on the board

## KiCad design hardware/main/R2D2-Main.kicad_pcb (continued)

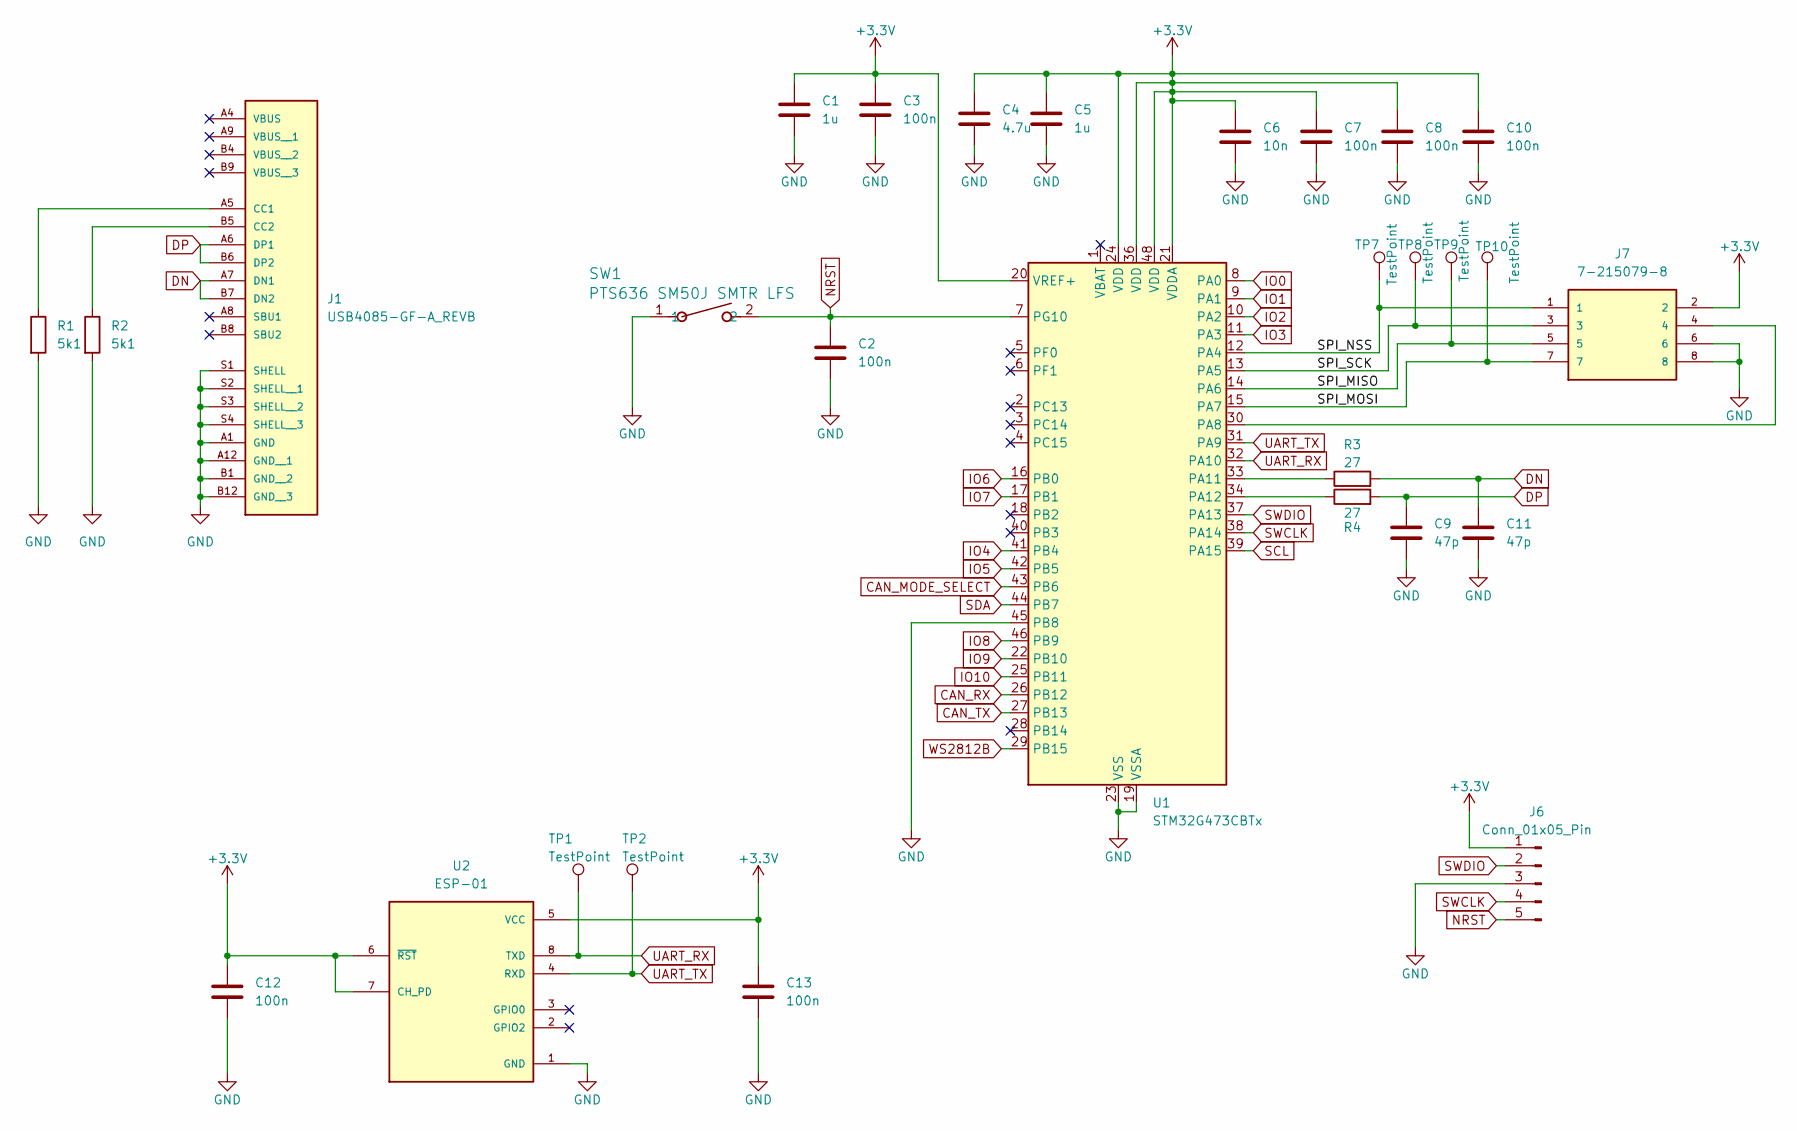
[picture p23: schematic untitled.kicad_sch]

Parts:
C1, C5: 1u; C_0603_1608Metric_Pad1.08x0.95mm_HandSolder
C2, C3, C7, C8, C10, C12, C13: 100n; C_0603_1608Metric_Pad1.08x0.95mm_HandSolder
C4: 4.7u; C_0603_1608Metric_Pad1.08x0.95mm_HandSolder
C6: 10n; C_0603_1608Metric_Pad1.08x0.95mm_HandSolder
C9, C11: 47p; C_0603_1608Metric_Pad1.08x0.95mm_HandSolder
J1: USB4085-GF-A_REVB; GCT_USB4085-GF-A_REVB; PARTREV B
J6: Conn_01x05_Pin; PinHeader_1x05_P2.54mm_Vertical
J7: 7-215079-8; TE_7-215079-8; PARTREV Y1
R1, R2: 5k1; R_0603_1608Metric_Pad0.98x0.95mm_HandSolder
R3, R4: 27; R_0603_1608Metric_Pad0.98x0.95mm_HandSolder
SW1: PTS636 SM50J SMTR LFS; SW_PTS636_CNK
TP1, TP2, TP7, TP8, TP9, TP10: TestPoint; TestPoint_Pad_D1.0mm
U1: STM32G473CBTx; LQFP48-7x7mm
U2: ESP-01; MODULE_ESP-01; PARTREV 1.0

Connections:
+3.3V: C1.1, C3.1, C4.1, C5.1, C6.1, C7.1, C8.1, C10.1, C12.1, C13.1, J6.1, J7.2, U1.20 (VREF+), U1.21 (VDDA), U1.24 (VDD), U1.36 (VDD), U1.48 (VDD), U2.5 (VCC), U2.6 (~RST), U2.7 (CH_PD); also elsewhere on the board
/Untitled Sheet/SPI_MISO: J7.5, TP9.1, U1.14 (PA6)
/Untitled Sheet/SPI_MOSI: J7.7, TP10.1, U1.15 (PA7)
/Untitled Sheet/SPI_NSS: J7.1, TP7.1, U1.12 (PA4)
/Untitled Sheet/SPI_SCK: J7.3, TP8.1, U1.13 (PA5)
CAN_MODE_SELECT: U1.43 (PB6); also elsewhere on the board
CAN_RX: U1.26 (PB12); also elsewhere on the board
CAN_TX: U1.27 (PB13); also elsewhere on the board
DN: C11.1, J1.A7 (DN1), J1.B7 (DN2), R3.2
DP: C9.1, J1.A6 (DP1), J1.B6 (DP2), R4.2
GND: C1.2, C2.2, C3.2, C4.2, C5.2, C6.2, C7.2, C8.2, C9.2, C10.2, C11.2, C12.2, C13.2, J1.A1 (GND), J1.A12 (GND__1), J1.B1 (GND__2), J1.B12 (GND__3), J1.S1 (SHELL), J1.S2 (SHELL__1), J1.S3 (SHELL__2), J1.S4 (SHELL__3), J6.3, J7.6, J7.8, R1.2, R2.2, SW1.1, U1.19 (VSSA), U1.23 (VSS), U1.35 (VSS), U1.45 (PB8), U1.47 (VSS), U2.1 (GND); also elsewhere on the board
IO0: U1.8 (PA0); also elsewhere on the board
IO1: U1.9 (PA1); also elsewhere on the board
IO2: U1.10 (PA2); also elsewhere on the board
IO3: U1.11 (PA3); also elsewhere on the board
IO4: U1.41 (PB4); also elsewhere on the board
IO5: U1.42 (PB5); also elsewhere on the board
IO6: U1.16 (PB0); also elsewhere on the board
IO7: U1.17 (PB1); also elsewhere on the board
IO8: U1.46 (PB9); also elsewhere on the board
IO9: U1.22 (PB10); also elsewhere on the board
IO10: U1.25 (PB11); also elsewhere on the board
NRST: C2.1, J6.5, SW1.2, U1.7 (PG10)
unnamed: J1.A5 (CC1), R1.1
unnamed: J1.B5 (CC2), R2.1
unnamed: J7.4, U1.30 (PA8)
unnamed: R3.1, U1.33 (PA11)
unnamed: R4.1, U1.34 (PA12)
SCL: U1.39 (PA15); also elsewhere on the board
SDA: U1.44 (PB7); also elsewhere on the board
SWCLK: J6.4, U1.38 (PA14)
SWDIO: J6.2, U1.37 (PA13)
UART_RX: TP1.1, U1.32 (PA10), U2.8 (TXD)
UART_TX: TP2.1, U1.31 (PA9), U2.4 (RXD)
WS2812B: U1.29 (PB15); also elsewhere on the board

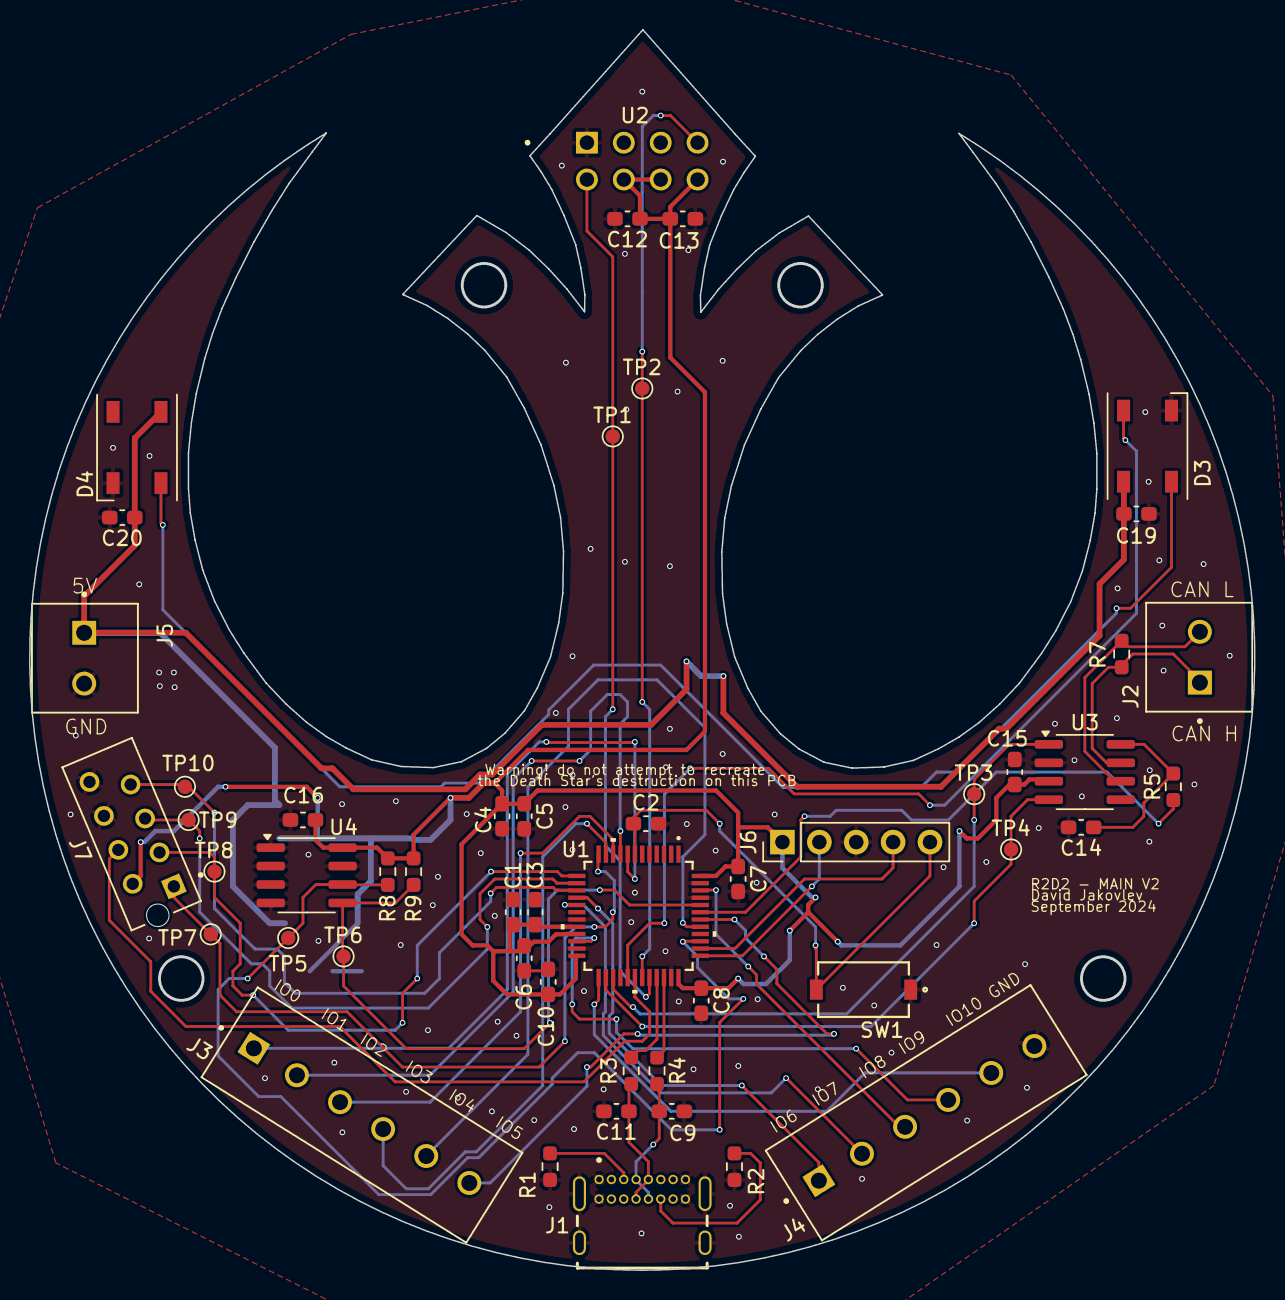
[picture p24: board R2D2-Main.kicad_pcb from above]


Board: 2 copper layers, 84.4 x 85.4 mm, 56 parts (6 on the bottom side), 41 nets.

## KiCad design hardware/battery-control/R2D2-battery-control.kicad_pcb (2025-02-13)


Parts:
C1, C2, C4, C5, C6, C8, C12: 100n; C_0603_1608Metric_Pad1.08x0.95mm_HandSolder
C3: 4.7u; C_0603_1608Metric_Pad1.08x0.95mm_HandSolder
C7: 1u; C_0603_1608Metric_Pad1.08x0.95mm_HandSolder
D1: BAT54C; SOT-23
J1, J2: 1751248; PHOENIX_1751248; PARTREV 03.03.2021
J3: Conn_01x05_Pin; PinHeader_1x05_P2.54mm_Horizontal
R1, R3, R4, R8, R9: 10k; R_0603_1608Metric_Pad0.98x0.95mm_HandSolder
R2: 120; R_0603_1608Metric_Pad0.98x0.95mm_HandSolder; not fitted
SW1: PTS636 SM50J SMTR LFS; SW_PTS636_CNK
TP1, TP2, TP3, TP4, TP5: TestPoint; TestPoint_Pad_D1.0mm
U1: SN65HVD230; SOIC-8_3.9x4.9mm_P1.27mm
U2: STM32F042F6Px; TSSOP-20_4.4x6.5mm_P0.65mm
U6: TMP1075NDRLR; SOT50P160X60-6N; PARTREV E

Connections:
+3.3V: C2.1, C3.1, C5.1, C6.1, C7.1, C8.1, C12.1, D1.3, J3.1, R8.2, R9.2, U1.3 (VCC), U2.5 (VDDA), U2.16 (VDD), U6.5 (V+); also elsewhere on the board
/controller/CAN+: J1.01, J2.01, R2.2, U1.7 (CANH)
/controller/CAN-: J1.02, J2.02, R2.1, U1.6 (CANL)
CAN_MODE_SELECT: R1.2, U2.13 (PA7)
CAN_RX: TP2.1, U1.4 (R), U2.17 (PA9/PA11)
CAN_TX: TP1.1, U1.1 (D), U2.18 (PA10/PA12)
CURRENT_ADC: R4.2, TP3.1; also elsewhere on the board
CURRENT_ADC_REF: TP5.1, U2.10 (PA4); also elsewhere on the board
GND: C1.2, C2.2, C3.2, C4.2, C5.2, C6.2, C7.2, C8.2, C12.2, J3.3, SW1.1, U1.2 (GND), U2.15 (VSSA), U6.2 (GND), U6.4 (A0); also elsewhere on the board
NRST: C4.1, J3.5, SW1.2, U2.4 (NRST)
unnamed: C1.1, R1.1, U1.8 (Rs)
unnamed: D1.1, R3.1, U2.8 (PA2)
unnamed: D1.2, R4.1, U2.9 (PA3)
RELAY_CTL: U2.12 (PA6); also elsewhere on the board
SCL: R8.1, U2.3 (PF1), U6.1 (SCL)
SDA: R9.1, U2.2 (PF0), U6.6 (SDA)
SWCLK: J3.4, U2.20 (PA14)
SWDIO: J3.2, U2.19 (PA13)
TEMP_ALERT: U2.11 (PA5), U6.3 (ALERT)
VOLTAGE_ADC: R3.2, TP4.1; also elsewhere on the board


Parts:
C9: 10u; C_0603_1608Metric_Pad1.08x0.95mm_HandSolder
C10: 22u; C_0603_1608Metric_Pad1.08x0.95mm_HandSolder
C11: 100n; C_0603_1608Metric_Pad1.08x0.95mm_HandSolder
D2: 12V-LL41; D_MiniMELF
D3: D; D_SMA
D4: LED; LED_0603_1608Metric
J4, J5: 1935776; PHOENIX_1935776; PARTREV 19.10.2016
K1: J123F1C12VDC.36; RELAY5_J123F1C5VDC.36_CRS
L1: 2.2uH; L_0805_2012Metric
Q1: T2N7002AK; SOT-23
R5: 100k; R_0603_1608Metric_Pad0.98x0.95mm_HandSolder
R6, R7: 10k; R_0603_1608Metric_Pad0.98x0.95mm_HandSolder
R10: 1k; R_0603_1608Metric_Pad0.98x0.95mm_HandSolder
U3: TPS62172DSGR; SON50P200X200X80-9N
U4: LM321; SOT-23-5
U5: ACS37010

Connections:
+3.3V: C10.1, C11.1, L1.2, R5.2, R10.2, U3.6 (VOS), U5.8 (VDD); also elsewhere on the board
+12V: J5.2, K1.1
/Power Stage/VDD_IN: J4.1, U5.1 (IP+)
CURRENT_ADC: U5.7 (VOUT); also elsewhere on the board
CURRENT_ADC_REF: U5.6 (VREF); also elsewhere on the board
GND: C9.2, C10.2, C11.2, D4.1 (K), J4.2, J5.1, Q1.2 (S), R6.1, R7.1, U3.1 (PGND), U3.4 (AGND), U3.5 (FB), U3.9 (EPAD), U4.2 (V-), U5.5 (GND); also elsewhere on the board
unnamed: D2.1 (K), U4.3 (-), U4.4
unnamed: D3.2 (A), K1.4, Q1.3 (D)
unnamed: D4.2 (A), R10.1
unnamed: R5.1, U3.8 (PG)
unnamed: L1.1, U3.7 (SW)
RELAY_CTL: Q1.1 (G), R6.2; also elsewhere on the board
VDD: C9.1, D3.1 (K), K1.2, K1.3, U3.2 (VLN), U3.3 (EN), U4.1 (+), U4.5 (V+), U5.4 (IP-)
VOLTAGE_ADC: D2.2 (A), R7.2; also elsewhere on the board



Board: 2 copper layers, 57.0 x 37.0 mm, 46 parts (6 on the bottom side), 28 nets.

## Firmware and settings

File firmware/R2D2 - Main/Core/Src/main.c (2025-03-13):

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
/* Includes ------------------------------------------------------------------*/
#include "main.h"
#include "usb_device.h"

/* USER CODE BEGIN Includes */
#include "stdbool.h"
#include "math.h"
#include "ili9341.h"
#include "ili9341_gfx.h"
#include "bmp.h"
/* USER CODE END Includes */

/* USER CODE BEGIN PD */
#define SECTOR_TOP 0;
#define SECTOR_RIGHT 1;
#define SECTOR_BOTTOM 2;
#define SECTOR_LEFT 3;
/* USER CODE END PD */

FDCAN_HandleTypeDef hfdcan2;

I2C_HandleTypeDef hi2c1;

SPI_HandleTypeDef hspi1;
DMA_HandleTypeDef hdma_spi1_tx;

TIM_HandleTypeDef htim1;
TIM_HandleTypeDef htim15;

UART_HandleTypeDef huart1;
DMA_HandleTypeDef hdma_usart1_rx;

/* USER CODE BEGIN PV */

extern const unsigned char bmp[];

// FDCAN2 Defines
FDCAN_TxHeaderTypeDef   TxHeaderDriveLeft;
FDCAN_TxHeaderTypeDef   TxHeaderDriveRight;
FDCAN_RxHeaderTypeDef   RxHeader1;
uint8_t               TxDataDriveLeft[4];
uint8_t               TxDataDriveRight[4];

uint8_t               RxData1[2];

uint32_t indx;

uint8_t speed;
volatile uint8_t uartRxData[10];
bool uartReceiveEvent;

int8_t joystickX;
int8_t joystickY;

uint8_t pwmDutyCycleLeft;
uint8_t pwmDutyCycleRight;

ili9341_t *_lcd;
ili9341_text_attr_t text;
ili9341_text_attr_t text_connected;
ili9341_text_attr_t text_disconnected;
ili9341_text_attr_t text_battery;

uint16_t lastPointerPositionLeft = 1;
int8_t lastPointerPositionDirectionLeft;
uint16_t lastPointerPositionRight = 1;
int8_t lastPointerPositionDirectionRight;

bool websocketConnected;
/* USER CODE END PV */

void SystemClock_Config(void);
static void MX_GPIO_Init(void);
static void MX_DMA_Init(void);
static void MX_FDCAN2_Init(void);
static void MX_I2C1_Init(void);
static void MX_SPI1_Init(void);
static void MX_USART1_UART_Init(void);
static void MX_TIM15_Init(void);
static void MX_TIM1_Init(void);
/* USER CODE BEGIN 0 */
float calculate_differential_drive_factor(int8_t joystickXpos, int8_t joystickYpos){
	if(joystickXpos > joystickYpos){
		return (1 - (float)joystickYpos / (float)joystickXpos);
	}
	else if(joystickYpos > joystickXpos){
		return (1 - (float)joystickXpos / (float)joystickYpos);
	}
	else{
		return 0;
	}
}

int8_t get_joystick_sector(int8_t joystickXpos, int8_t joystickYpos){
	if(joystickY > 0 && joystickYpos > joystickXpos){
		return SECTOR_BOTTOM;
	}
	else if(joystickX > 0 && joystickXpos > joystickYpos){
		return SECTOR_RIGHT;
	}
	else if(joystickY < 0 && joystickYpos > joystickXpos){
		return SECTOR_TOP;
	}
	else if(joystickX < 0 && joystickXpos > joystickYpos){
		return SECTOR_LEFT;
	}
	else{
		return -1;
	}
}

void calculate_pwm_values(int8_t sector, float differentialDriveFactor){
	if(sector == -1){
		pwmDutyCycleLeft = 0;
		pwmDutyCycleRight = 0;
		TxDataDriveLeft[2] = 'S';
		TxDataDriveRight[2] = 'S';
	}
	else{
		switch(sector){
		case 0: // move forward with steering
			TxDataDriveLeft[2] = 'F';
			TxDataDriveRight[2] = 'F';
			if(joystickX > 0){
				pwmDutyCycleLeft = speed;
				pwmDutyCycleRight = speed * differentialDriveFactor;
			}
			else{
				pwmDutyCycleLeft = speed * differentialDriveFactor;
				pwmDutyCycleRight = speed;
			}
			break;
		case 1: // rotate right
			TxDataDriveLeft[2] = 'F';
			TxDataDriveRight[2] = 'B';
			pwmDutyCycleLeft = speed;
			pwmDutyCycleRight = speed;
			break;
		case 2: // move backward with steering
			TxDataDriveLeft[2] = 'B';
			TxDataDriveRight[2] = 'B';
			if(joystickX > 0){
				pwmDutyCycleLeft = speed * differentialDriveFactor;
				pwmDutyCycleRight = speed;
			}
			else{
				pwmDutyCycleLeft = speed;
				pwmDutyCycleRight = speed * differentialDriveFactor;
			}
			break;
		case 3: // rotate left
			TxDataDriveLeft[2] = 'B';
			TxDataDriveRight[2] = 'F';
			pwmDutyCycleLeft = speed;
			pwmDutyCycleRight = speed;
			break;
		}
	}
}

void display_telemetry(void){
	uint16_t pointerPositionLeft = (pwmDutyCycleLeft - 50) * 1.6;
	if(lastPointerPositionLeft != pointerPositionLeft){
		if(lastPointerPositionDirectionLeft == 'F'){
			ili9341_fill_rect(_lcd, ILI9341_NAVY, 245, 97 - lastPointerPositionLeft, 15, 6);
		}
		else{
			ili9341_fill_rect(_lcd, ILI9341_NAVY, 245, 97 + lastPointerPositionLeft, 15, 6);
		}
		if(TxDataDriveLeft[0] == 'F'){
			ili9341_fill_rect(_lcd, ILI9341_RED, 245, 97 - pointerPositionLeft, 15, 6);
		}
		else{
			ili9341_fill_rect(_lcd, ILI9341_RED, 245, 97 + pointerPositionLeft, 15, 6);
		}
 		lastPointerPositionLeft = pointerPositionLeft;
 		lastPointerPositionDirectionLeft = TxDataDriveLeft[0];
	}

	uint16_t pointerPositionRight = (pwmDutyCycleRight - 50) * 1.6;
	if(lastPointerPositionRight != pointerPositionRight){
		if(lastPointerPositionDirectionRight == 'F'){
			ili9341_fill_rect(_lcd, ILI9341_NAVY, 275, 97 - lastPointerPositionRight, 15, 6);
		}
		else{
			ili9341_fill_rect(_lcd, ILI9341_NAVY, 275, 97 + lastPointerPositionRight, 15, 6);
		}
		if(TxDataDriveRight[0] == 'F'){
			ili9341_fill_rect(_lcd, ILI9341_RED, 275, 97 - pointerPositionRight, 15, 6);
		}
		else{
			ili9341_fill_rect(_lcd, ILI9341_RED, 275, 97 + pointerPositionRight, 15, 6);
		}
		lastPointerPositionRight = pointerPositionRight;
		lastPointerPositionDirectionRight = TxDataDriveRight[0];
	}

	if(websocketConnected){
		ili9341_draw_string(_lcd, text_connected, "Connected    ");
	}
	else{
		ili9341_draw_string(_lcd, text_disconnected, "Disconnected!");
	}
}

void update_battery_indicator(uint8_t battery_level){
	ili9341_draw_rect(_lcd, ILI9341_BLACK, 160, 80, 40, 100);
	ili9341_fill_rect(_lcd, ILI9341_BLACK, 170, 71, 20, 10);

	if(battery_level <= 30){
		text_battery.fg_color = ILI9341_RED;
	}
	else{
		text_battery.fg_color = ILI9341_GREEN;
	}

	char text[5];
	snprintf(text, sizeof(text), "%-3d%%", battery_level);
	ili9341_draw_string(_lcd, text_battery, text);

	if(battery_level >= 75){
		ili9341_fill_rect(_lcd, ILI9341_GREEN, 165, 85, 30, 19);
		ili9341_fill_rect(_lcd, ILI9341_GREEN, 165, 109, 30, 19);
		ili9341_fill_rect(_lcd, ILI9341_GREEN, 165, 133, 30, 19);
		ili9341_fill_rect(_lcd, ILI9341_GREEN, 165, 157, 30, 19);
	}
	else if(battery_level >= 50){
		ili9341_fill_rect(_lcd, ILI9341_NAVY, 165, 85, 30, 19);
		ili9341_fill_rect(_lcd, ILI9341_GREEN, 165, 109, 30, 19);
		ili9341_fill_rect(_lcd, ILI9341_GREEN, 165, 133, 30, 19);
		ili9341_fill_rect(_lcd, ILI9341_GREEN, 165, 157, 30, 19);
	}
	else if(battery_level >= 25){
		ili9341_fill_rect(_lcd, ILI9341_NAVY, 165, 85, 30, 19);
		ili9341_fill_rect(_lcd, ILI9341_NAVY, 165, 109, 30, 19);
		ili9341_fill_rect(_lcd, ILI9341_GREEN, 165, 133, 30, 19);
		ili9341_fill_rect(_lcd, ILI9341_GREEN, 165, 157, 30, 19);
	}
	else{
		ili9341_fill_rect(_lcd, ILI9341_NAVY, 165, 85, 30, 19);
		ili9341_fill_rect(_lcd, ILI9341_NAVY, 165, 109, 30, 19);
		ili9341_fill_rect(_lcd, ILI9341_NAVY, 165, 133, 30, 19);
		ili9341_fill_rect(_lcd, ILI9341_RED, 165, 157, 30, 19);
	}
}
/* USER CODE END 0 */

/**
  * @brief  The application entry point.
  * @retval int
  */
int main(void)
{

  /* MCU Configuration--------------------------------------------------------*/

  /* Reset of all peripherals, Initializes the Flash interface and the Systick. */
  HAL_Init();

  /* Configure the system clock */
  SystemClock_Config();

  /* Initialize all configured peripherals */
  MX_GPIO_Init();
  MX_DMA_Init();
  MX_FDCAN2_Init();
  MX_I2C1_Init();
  MX_SPI1_Init();
  MX_USART1_UART_Init();
  MX_TIM15_Init();
  MX_USB_Device_Init();
  MX_TIM1_Init();
  /* USER CODE BEGIN 2 */

  if(HAL_FDCAN_Start(&hfdcan2)!= HAL_OK)
  {
   Error_Handler();
  }

  if (HAL_FDCAN_ActivateNotification(&hfdcan2, FDCAN_IT_RX_FIFO0_NEW_MESSAGE, 0) != HAL_OK)
  {
    /* Notification Error */
    Error_Handler();
  }

  // Configure TX Header for FDCAN1
  TxHeaderDriveLeft.Identifier = 0x12;
  TxHeaderDriveLeft.IdType = FDCAN_STANDARD_ID;
  TxHeaderDriveLeft.TxFrameType = FDCAN_DATA_FRAME;
  TxHeaderDriveLeft.DataLength = FDCAN_DLC_BYTES_4;
  TxHeaderDriveLeft.ErrorStateIndicator = FDCAN_ESI_ACTIVE;
  TxHeaderDriveLeft.BitRateSwitch = FDCAN_BRS_OFF;
  TxHeaderDriveLeft.FDFormat = FDCAN_CLASSIC_CAN;
  TxHeaderDriveLeft.TxEventFifoControl = FDCAN_NO_TX_EVENTS;
  TxHeaderDriveLeft.MessageMarker = 0;
  TxDataDriveLeft[0] = 0x10;
  TxDataDriveLeft[1] = 0x00;

  TxHeaderDriveRight.Identifier = 0x13;
  TxHeaderDriveRight.IdType = FDCAN_STANDARD_ID;
  TxHeaderDriveRight.TxFrameType = FDCAN_DATA_FRAME;
  TxHeaderDriveRight.DataLength = FDCAN_DLC_BYTES_4;
  TxHeaderDriveRight.ErrorStateIndicator = FDCAN_ESI_ACTIVE;
  TxHeaderDriveRight.BitRateSwitch = FDCAN_BRS_OFF;
  TxHeaderDriveRight.FDFormat = FDCAN_CLASSIC_CAN;
  TxHeaderDriveRight.TxEventFifoControl = FDCAN_NO_TX_EVENTS;
  TxHeaderDriveRight.MessageMarker = 0;
  TxDataDriveRight[0] = 0x10;
  TxDataDriveRight[1] = 0x00;

  HAL_Delay(1000); // give the ESP01 time to boot (the ESP sends unknown data over UART on boot)
  HAL_UART_Receive_DMA(&huart1, (uint8_t *)uartRxData, sizeof(uartRxData));

  _lcd = ili9341_new(
        &hspi1,
        RST_GPIO_Port, RST_Pin,
        SPI_NSS_GPIO_Port,    SPI_NSS_Pin,
        DC_GPIO_Port,    DC_Pin,
        isoLandscape,
        TOUCH_CS_GPIO_Port,  TOUCH_CS_Pin,
        TOUCH_IRQ_GPIO_Port, TOUCH_IRQ_Pin,
        itsSupported,
        itnNormalized);

  text.bg_color = ILI9341_NAVY;
  text.fg_color = ILI9341_WHITE;
  text.font = &ili9341_font_16x26;
  text.origin_x = 30;
  text.origin_y = 210;

  text_connected.bg_color = ILI9341_NAVY;
  text_connected.fg_color = ILI9341_GREEN;
  text_connected.font = &ili9341_font_7x10;
  text_connected.origin_x = 140;
  text_connected.origin_y = 10;

  text_disconnected.bg_color = ILI9341_NAVY;
  text_disconnected.fg_color = ILI9341_RED;
  text_disconnected.font = &ili9341_font_7x10;
  text_disconnected.origin_x = 140;
  text_disconnected.origin_y = 10;

  text_battery.bg_color = ILI9341_NAVY;
  text_battery.fg_color = ILI9341_GREEN;
  text_battery.font = &ili9341_font_7x10;
  text_battery.origin_x = 165;
  text_battery.origin_y = 60;

  ili9341_fill_screen(_lcd, ILI9341_NAVY);
  ili9341_draw_string(_lcd, text, "R2D2 Version 0.1");
  ili9341_draw_string(_lcd, text_disconnected, "Disconnected!");
  ili9341_draw_rect(_lcd, ILI9341_WHITE, 220, 20, 25, 160);
  ili9341_draw_rect(_lcd, ILI9341_WHITE, 290, 20, 25, 160);

  update_battery_indicator(20);

//  ili9341_draw_bitmap_1b(_lcd, ILI9341_WHITE, ILI9341_NAVY, 100, 100, 4, 4, bmp);
  ili9341_draw_bitmap_1b(_lcd, ILI9341_NAVY, ILI9341_WHITE,
          1, 3, 130, 200, (uint8_t *)bmp);

  HAL_TIM_Base_Start_IT(&htim1);
  /* USER CODE END 2 */

  /* Infinite loop */
  /* USER CODE BEGIN WHILE */
  while (1)
  {
	   if(uartReceiveEvent){
		   if(uartRxData[0] == 'M'){
			   joystickX = atoi((uint8_t *)&uartRxData[1]);
			   joystickY = atoi((uint8_t *)&uartRxData[5]);

			   speed = 0.393700787 * (float)sqrt(joystickX * joystickX + joystickY * joystickY) + 50.0;
			   if(speed > 100){
				   speed = 100;
			   }

			   uint8_t joystickXpos = (joystickX < 0) ? -joystickX : joystickX;
			   uint8_t joystickYpos = (joystickY < 0) ? -joystickY : joystickY;
			   float differentialDriveFactor = calculate_differential_drive_factor(joystickXpos, joystickYpos);
			   int8_t sector = get_joystick_sector(joystickXpos, joystickYpos);
			   calculate_pwm_values(sector, differentialDriveFactor);

			   TxDataDriveLeft[3] = pwmDutyCycleLeft;
			   TxDataDriveRight[3] = pwmDutyCycleRight;

			   HAL_FDCAN_AddMessageToTxFifoQ(&hfdcan2, &TxHeaderDriveLeft, TxDataDriveLeft);
			   HAL_Delay(2);
			   HAL_FDCAN_AddMessageToTxFifoQ(&hfdcan2, &TxHeaderDriveRight, TxDataDriveRight);
		   }
		   else if(uartRxData[0] == 'L'){

		   }
		   else if(uartRxData[0] == 'R'){

		   }
		   else if(uartRxData[0] == 'S'){

		   }
		   else if(strstr(uartRxData, 'connect')){
			   if(uartRxData[0] == '!'){
				   websocketConnected = false;
			   }
			   else{
				   websocketConnected = true;
			   }
		   }
		   uartReceiveEvent = false;
	   }

	   display_telemetry();

    /* USER CODE END WHILE */

    /* USER CODE BEGIN 3 */
  }
  /* USER CODE END 3 */
}

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
/* USER CODE BEGIN 4 */
void HAL_UART_RxCpltCallback(UART_HandleTypeDef *huart){
	uartReceiveEvent = true;
	__HAL_TIM_SET_COUNTER(&htim1, 0);
	websocketConnected = true;
}

void HAL_TIM_PeriodElapsedCallback(TIM_HandleTypeDef *htim){
	websocketConnected = false;
}

// FDCAN1 Callback
void HAL_FDCAN_RxFifo0Callback(FDCAN_HandleTypeDef *hfdcan, uint32_t RxFifo0ITs)
{
  if((RxFifo0ITs & FDCAN_IT_RX_FIFO0_NEW_MESSAGE) != RESET)
  {
    /* Retreive Rx messages from RX FIFO0 */
    if (HAL_FDCAN_GetRxMessage(hfdcan, FDCAN_RX_FIFO0, &RxHeader1, RxData1) != HAL_OK)
    {
    /* Reception Error */
    Error_Handler();
    }

    if (HAL_FDCAN_ActivateNotification(hfdcan, FDCAN_IT_RX_FIFO0_NEW_MESSAGE, 0) != HAL_OK)
    {
      /* Notification Error */
      Error_Handler();
    }
  }
}
/* USER CODE END 4 */
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


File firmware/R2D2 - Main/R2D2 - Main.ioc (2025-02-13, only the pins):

Mcu.UserName=STM32G473CBTx
PA0.GPIO_Label=TOUCH_CS
PA0.Signal=GPIO_Output
PA1.GPIO_Label=TOUCH_IRQ
PA1.Signal=GPIO_Output
PA10.Signal=USART1_RX
PA11.Signal=USB_DM
PA12.Signal=USB_DP
PA13.Signal=SYS_JTMS-SWDIO
PA14.Signal=SYS_JTCK-SWCLK
PA15.Signal=I2C1_SCL
PA3.GPIO_Label=RST
PA3.Signal=GPIO_Output
PA4.GPIO_Label=SPI_NSS
PA4.Signal=GPIO_Output
PA5.Signal=SPI1_SCK
PA6.Signal=SPI1_MISO
PA7.Signal=SPI1_MOSI
PA8.GPIO_Label=DC
PA8.Signal=GPIO_Output
PA9.Signal=USART1_TX
PB12.Signal=FDCAN2_RX
PB13.Signal=FDCAN2_TX
PB15.Signal=S_TIM15_CH2
PB6.GPIO_Label=CAN_MODE_SELECT
PB6.Signal=GPIO_Output
PB7.Signal=I2C1_SDA

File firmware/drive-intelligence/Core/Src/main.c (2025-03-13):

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
/* Includes ------------------------------------------------------------------*/
#include "main.h"

/* USER CODE BEGIN Includes */
#include "lsm6dsm_reg.h"
#include <stdio.h>
#include <stdarg.h>
#include <string.h>
#include <math.h>
/* USER CODE END Includes */

/* USER CODE BEGIN PD */
#define    SENSOR_BUS hi2c1

#define IDLE   0
#define DONE   1
#define F_CLK  10000000UL
/* USER CODE END PD */

CAN_HandleTypeDef hcan;

I2C_HandleTypeDef hi2c1;

TIM_HandleTypeDef htim3;

/* USER CODE BEGIN PV */
volatile uint8_t gu8_State = IDLE;
volatile uint8_t gu8_MSG[35] = {'\0'};
volatile uint32_t gu32_T1 = 0;
volatile uint32_t gu32_T2 = 0;
volatile uint32_t gu32_Ticks = 0;
volatile uint16_t gu16_TIM2_OVC = 0;
volatile uint32_t gu32_Freq = 0;
volatile float f_meters_per_second = 0;

uint32_t canAddress;
uint32_t driveCanAddress;
CAN_TxHeaderTypeDef TxHeaderDrive;
CAN_TxHeaderTypeDef TxHeaderMain;
uint8_t TxHeaderDriveData[6];
uint32_t TxMailbox;

static int16_t data_raw_acceleration[3];
static int16_t data_raw_angular_rate[3];
static int16_t data_raw_temperature;
static float acceleration_mg[3];
static float angular_rate_mdps[3];
static float temperature_degC;
static uint8_t whoamI, rst;
stmdev_ctx_t dev_ctx;
/* USER CODE END PV */

void SystemClock_Config(void);
static void MX_GPIO_Init(void);
static void MX_CAN_Init(void);
static void MX_I2C1_Init(void);
static void MX_TIM3_Init(void);
/* USER CODE BEGIN PFP */
static int32_t platform_write(void *handle, uint8_t reg, const uint8_t *bufp, uint16_t len);
static int32_t platform_read(void *handle, uint8_t reg, uint8_t *bufp, uint16_t len);
void lsm6_init(void);
void get_lsm6_data(void);
/* USER CODE END PFP */

/**
  * @brief  The application entry point.
  * @retval int
  */
int main(void)
{

  /* MCU Configuration--------------------------------------------------------*/

  /* Reset of all peripherals, Initializes the Flash interface and the Systick. */
  HAL_Init();

  /* Configure the system clock */
  SystemClock_Config();

  /* Initialize all configured peripherals */
  MX_GPIO_Init();
  MX_CAN_Init();
  MX_I2C1_Init();
  MX_TIM3_Init();
  /* USER CODE BEGIN 2 */
  TxHeaderDrive.IDE = CAN_ID_STD;
  TxHeaderDrive.StdId = driveCanAddress;
  TxHeaderDrive.RTR = CAN_RTR_DATA;
  TxHeaderDrive.DLC = 5;
  TxHeaderDriveData[0] = driveCanAddress;
  TxHeaderDriveData[1] = 0x01;

  TxHeaderMain.IDE = CAN_ID_STD;
  TxHeaderMain.StdId = driveCanAddress;
  TxHeaderMain.RTR = CAN_RTR_DATA;
  TxHeaderMain.DLC = 2;

  HAL_Delay(100);
  lsm6_init();
  /* USER CODE END 2 */

  /* Infinite loop */
  /* USER CODE BEGIN WHILE */
  while (1)
  {
	  uint32_t f_int = *(uint32_t*) &f_meters_per_second;
	  // Convert the integer to a byte array
	  for (int i = 2; i < sizeof(f_int) + 2; i++) {
		  TxHeaderDriveData[i] = (char) (f_int >> (8 * (sizeof(float) - 1 - i)));
	  }
	  HAL_CAN_AddTxMessage(&hcan, &TxHeaderDrive, TxHeaderDriveData, &TxMailbox);

	  get_lsm6_data();
    /* USER CODE END WHILE */

    /* USER CODE BEGIN 3 */
  }
  /* USER CODE END 3 */
}

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
/* USER CODE BEGIN 4 */

void lsm6_init(void){
	dev_ctx.write_reg = platform_write;
	dev_ctx.read_reg = platform_read;
	dev_ctx.handle = &SENSOR_BUS;

	lsm6dsm_i2c_interface_set(&dev_ctx, 0);
	lsm6dsm_device_id_get(&dev_ctx, &whoamI);

	do {
		lsm6dsm_reset_get(&dev_ctx, &rst);
	} while (rst);

	/*  Enable Block Data Update */
	lsm6dsm_block_data_update_set(&dev_ctx, PROPERTY_ENABLE);
	/* Set Output Data Rate for Acc and Gyro */
	lsm6dsm_xl_data_rate_set(&dev_ctx, LSM6DSM_XL_ODR_12Hz5);
	lsm6dsm_gy_data_rate_set(&dev_ctx, LSM6DSM_GY_ODR_12Hz5);
	/* Set full scale */
	lsm6dsm_xl_full_scale_set(&dev_ctx, LSM6DSM_2g);
	lsm6dsm_gy_full_scale_set(&dev_ctx, LSM6DSM_2000dps);
	/* Configure filtering chain(No aux interface)
	 * Accelerometer - analog filter
	 */
	lsm6dsm_xl_filter_analog_set(&dev_ctx, LSM6DSM_XL_ANA_BW_400Hz);
	/* Accelerometer - LPF1 path (LPF2 not used) */
	//lsm6dsm_xl_lp1_bandwidth_set(&dev_ctx, LSM6DSM_XL_LP1_ODR_DIV_4);
	/* Accelerometer - LPF1 + LPF2 path */
	lsm6dsm_xl_lp2_bandwidth_set(&dev_ctx, LSM6DSM_XL_LOW_NOISE_LP_ODR_DIV_100);
	/* Accelerometer - High Pass / Slope path */
	//lsm6dsm_xl_reference_mode_set(&dev_ctx, PROPERTY_DISABLE);
	//lsm6dsm_xl_hp_bandwidth_set(&dev_ctx, LSM6DSM_XL_HP_ODR_DIV_100);
	/* Gyroscope - filtering chain */
	lsm6dsm_gy_band_pass_set(&dev_ctx, LSM6DSM_HP_260mHz_LP1_STRONG);

	HAL_TIM_Base_Start_IT(&htim3);
	HAL_TIM_IC_Start_IT(&htim3, TIM_CHANNEL_4);
}

void get_lsm6_data(void){
	lsm6dsm_reg_t reg;
	/* Read output only if new value is available */
	lsm6dsm_status_reg_get(&dev_ctx, &reg.status_reg);

	if (reg.status_reg.xlda) {
		/* Read acceleration field data */
		memset(data_raw_acceleration, 0x00, 3 * sizeof(int16_t));
		lsm6dsm_acceleration_raw_get(&dev_ctx, data_raw_acceleration);
		acceleration_mg[0] = lsm6dsm_from_fs2g_to_mg(data_raw_acceleration[0]);
		acceleration_mg[1] = lsm6dsm_from_fs2g_to_mg(data_raw_acceleration[1]);
		acceleration_mg[2] = lsm6dsm_from_fs2g_to_mg(data_raw_acceleration[2]);
	}

	if (reg.status_reg.gda) {
		/* Read angular rate field data */
		memset(data_raw_angular_rate, 0x00, 3 * sizeof(int16_t));
		lsm6dsm_angular_rate_raw_get(&dev_ctx, data_raw_angular_rate);
		angular_rate_mdps[0] = lsm6dsm_from_fs2000dps_to_mdps(
				data_raw_angular_rate[0]);
		angular_rate_mdps[1] = lsm6dsm_from_fs2000dps_to_mdps(
				data_raw_angular_rate[1]);
		angular_rate_mdps[2] = lsm6dsm_from_fs2000dps_to_mdps(
				data_raw_angular_rate[2]);
	}

	if (reg.status_reg.tda) {
		/* Read temperature data */
		memset(&data_raw_temperature, 0x00, sizeof(int16_t));
		lsm6dsm_temperature_raw_get(&dev_ctx, &data_raw_temperature);
		temperature_degC = lsm6dsm_from_lsb_to_celsius(data_raw_temperature);
	}
}

/*
 * @brief  Write generic device register (platform dependent)
 *
 * @param  handle    customizable argument. In this examples is used in
 *                   order to select the correct sensor bus handler.
 * @param  reg       register to write
 * @param  bufp      pointer to data to write in register reg
 * @param  len       number of consecutive register to write
 *
 */
static int32_t platform_write(void *handle, uint8_t reg, const uint8_t *bufp, uint16_t len)
{
  HAL_I2C_Mem_Write(handle, LSM6DSM_I2C_ADD_L, reg, I2C_MEMADD_SIZE_8BIT, (uint8_t*) bufp, len, 1000);
  return 0;
}

/*
 * @brief  Read generic device register (platform dependent)
 *
 * @param  handle    customizable argument. In this examples is used in
 *                   order to select the correct sensor bus handler.
 * @param  reg       register to read
 * @param  bufp      pointer to buffer that store the data read
 * @param  len       number of consecutive register to read
 *
 */
static int32_t platform_read(void *handle, uint8_t reg, uint8_t *bufp, uint16_t len)
{
  HAL_I2C_Mem_Read(handle, LSM6DSM_I2C_ADD_L, reg, I2C_MEMADD_SIZE_8BIT, bufp, len, 1000);
  return 0;
}
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

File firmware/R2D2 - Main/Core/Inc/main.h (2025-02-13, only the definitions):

#define TOUCH_CS_Pin GPIO_PIN_0
#define TOUCH_CS_GPIO_Port GPIOA
#define TOUCH_IRQ_Pin GPIO_PIN_1
#define TOUCH_IRQ_GPIO_Port GPIOA
#define RST_Pin GPIO_PIN_3
#define RST_GPIO_Port GPIOA
#define SPI_NSS_Pin GPIO_PIN_4
#define SPI_NSS_GPIO_Port GPIOA
#define DC_Pin GPIO_PIN_8
#define DC_GPIO_Port GPIOA
#define CAN_MODE_SELECT_Pin GPIO_PIN_6
#define CAN_MODE_SELECT_GPIO_Port GPIOB

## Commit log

2025-02-13 initial source files
    [R2D2-Main.kicad_pcb, R2D2-Main.kicad_sch, R2D2-Main.step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]
2025-02-15 main firmware: added battery indicator to display
2025-02-16 main firmware: improved battery indicator for display
2025-03-04 fw: drive-intelligence: IMU sensor and speed measurement working
2025-03-05 hw: drive: added a solder jumper for CAN address
    [R2D2-drive.kicad_pcb, R2D2-drive.kicad_sch]
2025-03-05 fw: drive: added left/right motor detection through gpio
2025-03-09 hw: drive-intelligence: added solder jumper for left or right motor setting
    [R2D2-drive-intelligence.kicad_pcb, R2D2-drive-intelligence.kicad_sch]

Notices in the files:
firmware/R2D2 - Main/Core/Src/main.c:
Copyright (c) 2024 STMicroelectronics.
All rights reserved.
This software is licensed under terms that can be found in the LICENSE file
